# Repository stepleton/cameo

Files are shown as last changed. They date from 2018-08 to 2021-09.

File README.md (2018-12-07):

# Cameo

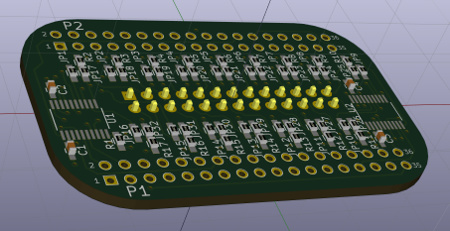
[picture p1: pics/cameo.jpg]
Cameo circuit board 3-D rendering


is a peripheral [cape](https://beagleboard.org/capes) circuit board that allows
the [PocketBeagle](http://beagleboard.org/pocket) single-board computer (which
uses 3.3V digital signals) to interface with 5V digital logic. It is built
around two Texas Instruments [TXS0108EPWR]( http://www.ti.com/product/TXS0108E)
or [TXB0108PWR]( http://www.ti.com/product/TXB0108) 8-bit bidirectional voltage
level translator ICs. Sixteen digital I/O signal lines are available.

Cameo is optimised for applications that take advantage of the two [PRU-ICSS](
https://beagleboard.org/pru) real-time coprocessors built into the chip-like
hybrid circuit that powers the PocketBeagle (a [TI AM3358](
http://www.ti.com/product/AM3358) SoC/[Octavo OSD3358](
https://octavosystems.com/octavo_products/osd335x/) SiP). The digital I/O lines
that pass through Cameo include all fourteen logic lines the PRUs can access
directly in either the input or output direction. The two remaining lines are
one that PRU 0 can use for output only and one it can use for input only, the
latter of which also happens to be the CLOCKIN line for the PRU's "parallel
capture" input mode. Alternatively, all lines may be used bidirectionally via
the AM3358's GPIO modules.

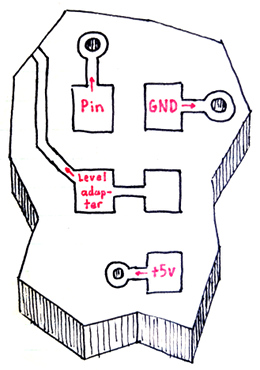
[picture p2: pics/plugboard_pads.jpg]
"Plugboard" diagram for a single pin

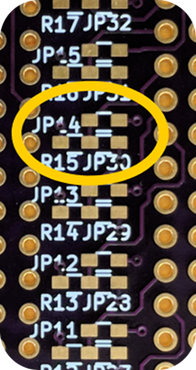
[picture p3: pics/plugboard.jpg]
Close-up of part of the "plugboard"


Cameo is "plugboard programmable": a pattern of jumper pads on the cape allow
each signal line to be individually tied/pulled to GND or +5V, or to be
[terminated](https://www.youtube.com/watch?v=rN9zjVK3Nrk) in a variety of ways,
all through installation of appropriate 0603 surface-mount components (or, in a
pinch, solder bridges or small fragments of wire). See the [plugboard pad map](
#plugboard-pad-map) for a diagram showing all of the "plugboard" pads.

## Fair warning

Cameo and associated hardware designs, software materials, and other resources
distributed alongside it are all made available for free with NO WARRANTY OF
ANY KIND. Any system that interfaces with Cameo could suffer malfunction, data
loss, physical damage, or other harms. Some of these effects could be permanent
and/or unrepairable. If you're not prepared to risk these consequences, don't
use Cameo.

## Example applications

* [Aphid installation Aphid](aphid/),
  a hardware emulator for Apple parallel port hard drives.

## Assembly and installation

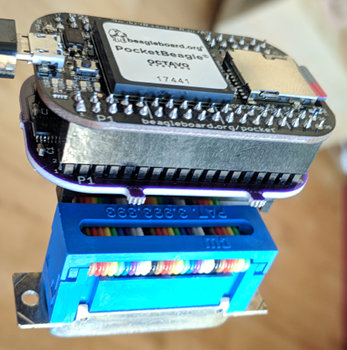
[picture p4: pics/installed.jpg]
A PocketBeagle/Cameo stack with a connector attached


Cameo is designed to mount underneath the PocketBeagle, preserving easy access
to the PocketBeagle's soft power button. The pin header for 5V digital I/O is
mounted on the underside of Cameo. With a short ribbon cable like the one in
the photo, the entire lightweight "stack" can dangle from a computer peripheral
port, as long as clearances and the security/fastness of the connector allow.

### Costs

To build a ready-to-use "stack" of your own from parts, you will need (prices
for informational purposes only; many are likely out-of-date):

* A PocketBeagle compact single-board computer ($25)
* A Cameo printed circuit board ($10 per board, **but sold only in packs of 3**
  from [OSH Park](https://www.oshpark.com/shared_projects/51GWu9Kw); shop around
  for deals by uploading the Gerber or KiCad project files in the
  [hardware directory](hardware) to online PCB manufacturers)
* Two TXS0108EPWR bidirectional level translator ICs ([e.g.](
  https://www.digikey.com/short/jr94zw); $1.66 each)
* Four 0.1μF MLCC 0603 surface mount capacitors ([e.g.](
  https://www.digikey.com/short/jr9znz); $0.10 each)
* One 240kΩ 0603 surface mount resistor ([e.g.](
  https://www.digikey.com/short/jrvd8z); $0.10 for just one)
* One 2x13 0.1" pitch pin header ([e.g.](https://www.digikey.com/short/jr9439);
  plastic shroud at your discretion; $0.30)
* Two 2x18 0.1" pitch pin headers ([e.g.](https://www.digikey.com/short/jr94b9);
  $0.69 each)
* Two 2x18 0.1" pitch sockets ([e.g.](https://www.digikey.com/short/jr94rq);
  $2.06 each)
* microSD memory card, 4GB or more, class 10 or better ($7 or so)
* Jumper and termination 0603 surface-mount components for I/O pins as required
  by your application (assuming the [Aphid](aphid/) configuration with 3 0Ω
  jumpers ([e.g.](https://www.digikey.com/short/jr9m80)) and 13 100Ω inline
  terminating resistors ([e.g.](https://www.digikey.com/short/j1rr2w)), $0.53
  altogether; jumpers are free if you make your own from scrap wire)

costing $52.15 in total. If you are willing to bond the PocketBeagle and Cameo
together permanently, you can omit the 2x18 sockets and save a bit over $4.

Some applications may benefit from adapting the 26-pin header on the bottom of
Cameo to a 25-pin DB-25 plug connector. To make this adaptor, you can use:

* 2x13 0.1" pitch socket with IDC crimp termination ([e.g.](
  https://www.digikey.com/short/jrbw3d), $0.58)
* DB-25 plug connector with IDC crimp termination ([e.g.](
  https://www.digikey.com/short/jrb2dj), $2.33)
* A short length (around 5cm) of 26-pin ribbon cable. ([e.g.](
  https://www.digikey.com/short/jrb2rr); $1.28 for a foot, ideally scrounged
  from a junk drawer for free)

adding to an additional $4.19.

### Assembly

Cameo is not an ideal starter project for hobbyists new to soldering
surface-mounted components; on the other hand, it doesn't have too many of
them, and they're not very tightly packed. The following diagram shows the
locations of essential SMD components on Cameo:

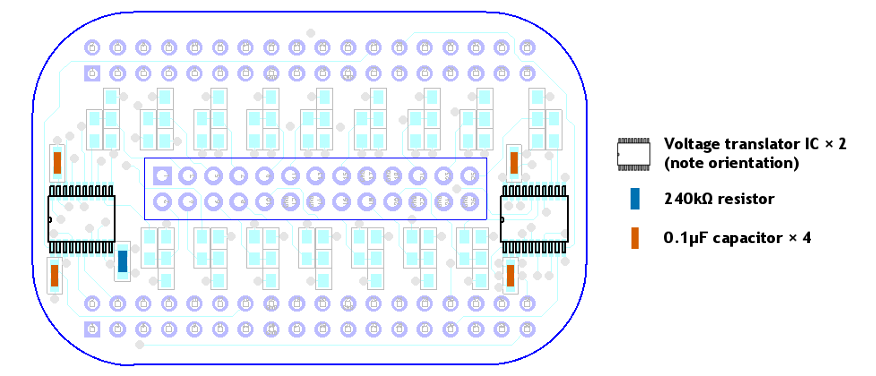
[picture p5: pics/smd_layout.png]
Locations of essential SMD components on Cameo


More SMD components will be required to set up the "plugboard" that connects
PocketBeagle signal lines to pins on the 5V I/O header. The specific nature and
configuration of these components are application-specific. See the
[introduction](#cameo) and the [plugboard pad map](#plugboard-pad-map) for more
details of the plugboard.

When assembling the Cameo board, it may be advisable to place the two voltage
translator ICs first, followed by the discrete SMD components and then by the
through-hole headers/connectors. **Remember, Cameo expects to be slung
underneath the PocketBeagle, so the 5V I/O header (centre) should emerge from
the bottom of the board, while the headers (or sockets) for connecting to the
PocketBeagle should emerge from the top.**

To connect to Cameo, the PocketBeagle will need sockets (or headers) emerging
from the **bottom** of its PCB. When mating Cameo to the PocketBeagle, be
certain of the correct orientation: if Cameo is orientated as shown above, the
USB connector on the PocketBeagle should be visible and pointing leftward.

Refer to online tutorials for making ribbon cable assemblies with IDC
connectors ([e.g.](https://startingelectronics.org/articles/IDC-ribbon-cable/))
to build an adaptor for the 5V I/O header. In general, it's best for the cable
between the two connectors to be as short as possible.

## Header pinout

The following pinout diagram represents Cameo's 26-pin 5V I/O header as viewed
from the underside of the Cameo PCB, with the PocketBeagle's USB connector
pointing upward.

| GPIO | PRU | PB pin | | Name | I/O pin | I/O pin | Name | | PB pin | PRU | GPIO |
|-----:|----:|---:|-|---:|:---:|:---:|:---|-|:---|:----|:-----|
| | | | | _n/c_  |  **1**  |  **2**  |  PEX3  | | P1.35  | 1 ⇆ | 2.24 |
| 1.10 | ⇆ 1 |  P1.32 | |  PEX1  |  **3**  |  **4**  | \PSTRB | | P2.9 | 0 ← | 0.15 |
| 1.11 | ⇆ 1 |  P1.30 | | PR/\W  |  **5**  |  **6**  | \PBSY  | | P2.35  | 1 ⇆ | 2.22 |
| 2.25 | ⇆ 1 | P1.4 | |  PEX2  |  **7**  |  **8**  | \PCMD  | | P1.2 | 1 ⇆ | 2.23 |
| 3.14 | ⇆ 0 |  P1.36 | | PD0  |  **9**  | **10**  |\PPARITY| | P2.24  | 0 → | 1.12 |
| 3.15 | ⇆ 0 |  P1.33 | | PD1  |  **11** | **12**  | ⏚ | | | | |
| | | | |  _n/c_ |  **13** | **14**  | ⏚ | | | | |
| 3.16 | ⇆ 0 |  P2.32 | | PD2  |  **15** | **16**  | _n/c_  | | | | |
| | | | | ⏚ |  **17** | **18**  |  PD3 | | P2.30  | 0 ⇆ | 3.17 |
| | | | | ⏚ |  **19** | **20**  |  PD4 | | P1.31  | 0 ⇆ | 3.18 |
| 3.19 | ⇆ 0 |  P2.34 | | PD5  |  **21** | **22**  | ⏚ | | | | |
| 3.20 | ⇆ 0 |  P2.28 | | PD6  |  **23** | **24**  | ⏚ | | | | |
| 3.21 | ⇆ 0 |  P1.29 | | PD7  |  **25** | **26**  | ⏚ | | | | |

The names of the 5V I/O pins reflect one of the example applications and should
be considered arbitrary. Pins marked _n/c_ connect to nothing; pins marked ⏚
are tied to ground.

The "PB pin" column shows which PocketBeagle header pin connects to Cameo's 5V
I/O header (through the 3.3V ⇆ 5V bidirectional voltage level translator ICs).

The "PRU" columns show which of the two PRU-ICSS real-time coprocessors in the
AM3358 are connected to each pin. A ⇆ symbol means that the corresponding
PocketBeagle pin can be configured either as an input to or an output of the
PRU; the ← and → symbols mean that the pin can only be a PRU input or output
respectively. Pins PD0-PD7 in particular map to PRU 0 GPIO bits 0-7.

The "GPIO" columns show how the pins correspond to I/O bits in the AM3358's
GPIO modules ("3.21" means module 3, bit 21). All pins may be accessed in any
direction through the GPIO subsystem.

For more detailed connectivity information, refer to the expansion header
tables in the [PocketBeagle reference manual](
https://github.com/beagleboard/pocketbeagle/wiki/System-Reference-Manual#71_Expansion_Header_Connectors).

Note finally that if an ordinary ribbon cable is used in an adaptor that
connects the 5V I/O header to a DB-25 plug connector, the pin numbering
patterns for both are different:

| DB-25 pin  | 1 | 2 | 3 | 4 | 5 |  6 |  7 |  8 |  9 | 10 | 11 | 12 | 13 |
|---|---|---|---|---|---|----|----|----|----|----|----|----|----|
| Header pin | 1 | 3 | 5 | 7 | 9 | 11 | 13 | 15 | 17 | 19 | 21 | 23 | 25 |

| DB-25 pin  | 14 | 15 | 16 | 17 | 18 | 19 | 20 | 21 | 22 | 23 | 24 | 25 |
|---|----|----|----|----|----|----|----|----|----|----|----|----|
| Header pin |  2 |  4 |  6 |  8 | 10 | 12 | 14 | 16 | 18 | 20 | 22 | 24 |

## Plugboard pad map

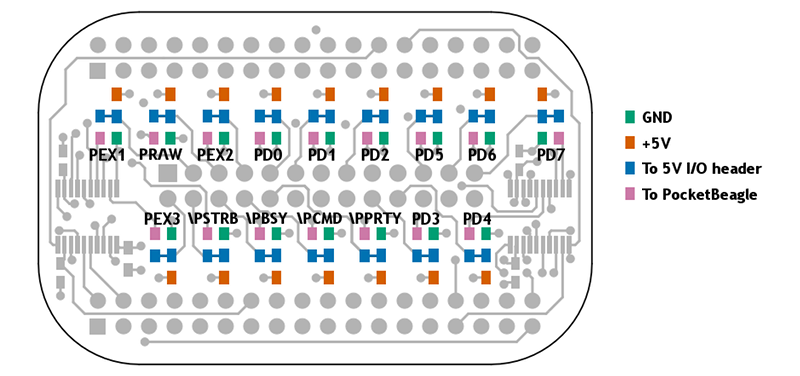
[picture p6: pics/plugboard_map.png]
Functional diagram of plugboard pads


This diagram shows a top-side view of Cameo. (In this view, the through-holes
for the 26-pin 5V I/O header (centre) are "flipped" about the header's long
(horizontal) axis, since the pins emerge from the underside of the board.)

The installation of jumpers, resistors, or other 0603 surface mount components
on each set of five pads shaped like ⠾, ⠻, or ⠷ determines whether and how the
labelled pin connects (through the voltage translator ICs) to the PocketBeagle.

## Development

Cameo was designed with [KiCad](http://kicad-pcb.org/) 4.  Project files and
derived products (Gerber files, etc.) are kept in the [hardware](hardware/)
subdirectory.

## Other notes

To the fullest extent possible, Cameo is released into the public domain.
Nobody owns Cameo.

## Acknowledgements

It would not have been possible for me to design Cameo without the help of the
following people and resources:

* Michael Welling's [pocketbeagle-cape-template](
  https://github.com/mwelling/pocketbeagle-cape-template).
* The [Sitara Processors Forum](https://e2e.ti.com/support/arm/sitara_arm) on
  the [TI E2E Community](https://e2e.ti.com/).
* Anonymous friends.

-- [_Tom Stepleton_](mailto:stepleton@gmail.com), 11 August 2018, London

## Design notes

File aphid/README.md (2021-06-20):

# Cameo/Aphid

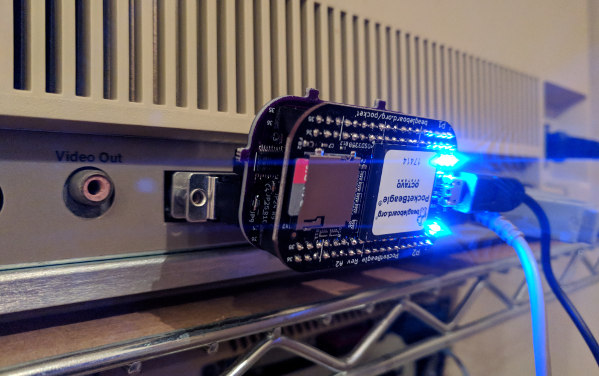
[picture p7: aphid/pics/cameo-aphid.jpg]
A PocketBeagle/Cameo stack with a connector attached


is a small Apple parallel port hard drive emulator based on the
[PocketBeagle](http://beagleboard.org/pocket) single-board computer and the
[Cameo](../README.md) 3.3V ⇄ 5V level adaptor cape. The hardware and software
described here aim to be a substitute for 5 MB (and also 10 MB) Apple
[ProFile](https://en.wikipedia.org/wiki/Apple_ProFile) external hard drives,
which were mainly used with Apple /// and Apple Lisa computers.

## Fair warning

Cameo/Aphid and associated hardware designs, software materials, and other
resources distributed alongside it are all made available for free with NO
WARRANTY OF ANY KIND. Any system that interfaces with Cameo/Aphid could suffer
malfunction, data loss, physical damage, or other harms. Some of these effects
could be permanent and/or unrepairable. If you're not prepared to risk these
consequences, don't use Cameo/Aphid.

**Additionally**: Cameo/Aphid is a new design that incorporates a number of
brand new, built-from-scratch software and hardware components. Although
considerable effort has been made to build a dependable emulator, Cameo/Aphid
still faces the test of time. It is possible, even likely, that some subtle
bugs have yet to be discovered and fixed.

## Gallery

Thumbnails link to high-resolution images, which may be helpful to people
assembling Cameo/Aphid. These images are not claimed to be illustrative of
good soldering technique.

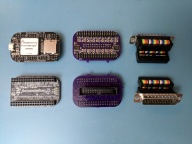
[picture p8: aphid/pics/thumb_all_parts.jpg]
Major Cameo/Aphid hardware components
[
Top and bottom views: PocketBeagle, Cameo, 5V I/O header to DB-25 adaptor.](
https://photos.app.goo.gl/s5zESxhNN7xtycam7)

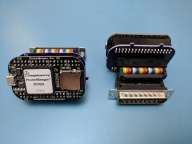
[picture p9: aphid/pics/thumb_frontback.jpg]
Cameo/Aphid hardware angled front and back views
[
Angled front and back views: Cameo/Aphid hardware components.](
https://photos.app.goo.gl/JWuywM5HkStonCPk9)

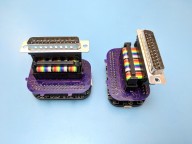
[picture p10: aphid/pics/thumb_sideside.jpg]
Cameo/Aphid hardware angled side views
[
Angled side views: Cameo/Aphid hardware components.](
https://photos.app.goo.gl/5HDvheUgoSHjGmFy6)

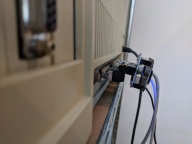
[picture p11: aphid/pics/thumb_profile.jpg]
Cameo/Aphid hardware on a Lisa, profile view
[
Profile view: Cameo/Aphid hardware installed on an Apple Lisa computer.](
https://photos.app.goo.gl/Pqm4weZKrUjdkRwC8)

A few additional photos are available in a [Google Images gallery](
https://photos.app.goo.gl/dgnkZrpXCz5ze1h9A).

## Usage

Cameo/Aphid is designed to be used in much the same way as a real ProFile hard
drive: it must be on and ready before the computer can be used; once the
computer is off again, Cameo/Aphid can be shut down and turned off.

Because Cameo/Aphid is based on the PocketBeagle, a single-board computer that
must boot an operating system to function, Cameo/Aphid takes longer to become
ready than a dedicated hardware emulator (e.g.
[X/ProFile](http://sigmasevensystems.com/xprofile), [IDEfile](
http://john.ccac.rwth-aachen.de:8000/patrick/idefile.htm)) does. Additionally,
like any modern computer (including the Apple Lisa), Cameo/Aphid prefers to
undergo a shutdown process before power is shut off.  To accomplish this at any
point after Cameo/Aphid is ready, press the [power button](
https://github.com/beagleboard/pocketbeagle/wiki/System-Reference-Manual#333_Powering_Down)
and wait for the "chasing lights" pattern (see below) to stop. It should only
take a few seconds.

(**UPDATE:** Full shutdown is not as important on Debian 9.5 and later OS
releases, as long as all the optional steps in the [installation instructions](
#full-instructions-for-manual-software-installation) have been carried out.
The [pre-made SD card image](#software-installation) was made in this way.
Robustness to power cuts is one step toward making Cameo/Aphid a suitable
replacement for Widget internal hard drives: further details of [improvements
targeting Widget replacement](#future-work) are below.)

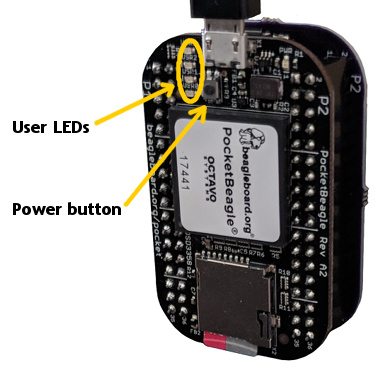
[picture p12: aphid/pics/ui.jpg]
Locations of the User LEDs and power button on the PocketBeagle


Cameo/Aphid uses the four "user LEDs" on the PocketBeagle to provide a visual
indication of its state. The light patterns you are most likely to see are
these:

1. **Just after Cameo/Aphid turns on**: The LEDs turn on one-by-one until all
   four are on.
2. **While the operating system is booting**: One LED is on nearly constantly,
   another blinks in a "heartbeat" rhythm; a third blinks with SD card access.
3. **While Cameo/Aphid software is starting up**: All four LEDs blink
   sequentially in a rapid "chasing" or "rotating" pattern. (**UPDATE:** This
   step will be skipped if all the non-optional steps in the [installation
   instructions](#full-instructions-for-manual-software-installation) are
   carried out, or if the [pre-made SD card image](#software-installation) is
   used.)
4. **When Cameo/Aphid is ready**: All four LEDs are on constantly.
5. **When Cameo/Aphid processes a disk command from the Apple**: All four LEDs
   blink off momentarily.
6. **During the shutdown process**: The chasing pattern resumes.
7. **When Cameo/Aphid is ready for power off**: The chasing pattern has frozen;
   at most one LED is on.

Finally, if Cameo/Aphid has encountered an unrecoverable error, the two central
user LEDs will slowly blink on and off. If this happens, try shutting down the
device by pressing the power button. Once the blinking stops, or if the power
button appears to have no effect after some time, try removing power from
Cameo/Aphid and then restoring it.

### Physical connections

Cameo/Aphid receives power from an ordinary Micro-B USB cable. Power
consumption data is hard to find for the PocketBeagle, but just about any USB
power source that can charge a phone reasonably well will probably work. A
computer with a USB-A port can supply power as well; don't be surprised by the
PocketBeagle's operating system making the PocketBeagle appear to be both a
network adaptor and a storage device.

Most installations will connect Cameo/Aphid to the Apple via a short adaptor
cable like the one described in the [main Cameo README.md](
../README.md#assembly). In this configuration, Cameo/Aphid dangles from the
Apple's DB-25 socket with no enclosure or physical support. If your Apple is
installed on an unpainted metal table or rack, take care that no components or
solder joints on the PocketBeagle or Cameo circuit boards rest on any metal
surface: stray electrical connections could result.

The electronics on the Cameo level translator cape do not work well with long
parallel cables. Little work has been carried out to determine the longest
cable that can work with Cameo/Aphid, but lengths between 50cm (20") and "as
short as possible" are probably preferable. Cameo/Aphid will work when attached
to a Widget hard drive ribbon cable inside a Lisa 2/10. Apple II users should
note that a typical Apple II ProFile interface card installation uses a
somewhat lengthy cable to connect the card to the parallel port. (Cameo/Aphid
has not yet been tested on an Apple II.)

### Hard drive images

Cameo/Aphid stores data from the simulated hard drive in an ordinary file on
the PocketBeagle's microSD card. This file has no metadata and a very simple
format: just as a 5 MB ProFile stores 5,175,296 bytes of data, a corresponding
hard drive image file is a 5,175,296-byte file; and just as a ProFile block is
532 bytes, each contiguous 532-byte chunk of the image file holds data from one
of the simulated drive's blocks. These blocks are arranged sequentially in the
file, starting from block $0000 and counting up to block $25FF.

(Aside: neither Cameo/Aphid nor the Apple parallel hard disk protocol itself
distinguish between "tag bytes" or "data bytes", even though these divisions of
a block are important to Lisas.)

Cameo/Aphid does not require image files to be only 5,175,296 bytes in size. A
10,350,592-byte image file causes Cameo/Aphid to emulate a 10 MB ProFile
(complete with the "spare table" data structure that announces it as such). An
enormous range of non-standard sizes are also supported: Cameo/Aphid will do
its best to serve hard drive image files of any size up to 8,890,613,228 bytes
(!), though images larger than a few dozen megabytes have not been tested.

(Note that many operating systems for your Apple will not know what to do with
hard drives that have non-standard sizes, and some older operating systems may
only work with 5 MB ProFiles.)

A microSD card initialised from the [pre-built software image](
#software-installation), or any other installation that makes use of a
[separate FAT32 partition for drive image storage](
#4-optional-prepare-a-separate-partition-for-cameoaphid-drive-images), can be
plugged into most modern computers and accessed like an ordinary flash drive.
Some computers may show two drives, one called `rootfs` and another called
`CAMEO_APHID`: the `CAMEO_APHID` drive is the home for hard drive images, and
`rootfs` should be left alone. (Windows users who don't see a drive after
plugging in their microSD cards may need to use the "Disk Management" or
"Create and format hard disk partitions" control panel to assign a drive letter
to the SD card's `CAMEO_APHID` partition.)

On the `CAMEO_APHID` drive, hard drive image files are any that end in
`.image`, with `profile.image` being the image file that Cameo/Aphid uses on
start-up.  It is fine to copy, rename, and otherwise manage hard drive image
files like any other kind of file, but Cameo/Aphid will not work if no file
called `profile.image` exists.

The operating system that runs on Cameo/Aphid's PocketBeagle computer is a
version of Debian Linux. In standard Cameo/Aphid setups, the `CAMEO_APHID`
partition is mounted at `/usr/local/lib/cameo-aphid`. If you have a network
connection to the PocketBeagle, which usually establishes automatically when
you plug a PocketBeagle into a modern computer's USB port, you can use ordinary
communications utilities (typically SSH, SCP) for command line access and file
transfer with the device. (For more guidance on connecting to your
PocketBeagle, see the [BeagleBone "Getting Started" guide](
http://beagleboard.org/getting-started). You may need to use the IP addresses
192.168.6.2 or 192.168.7.2 instead of the `beaglebone.local` convenience name.)

In the future, it may become possible to upload and download drive images via a
web browser.

:warning: **Be sure not to change or replace the hard drive image file while
the Apple is actively reading from or writing to the simulated disk drive.
After altering the image file, you must shut down and restart Cameo/Aphid
before the Apple attempts to access the drive.**

### For programmers

Cameo/Aphid allows the Apple to restart or shut down ProFile emulation via
specially-formatted writes. The Apple can use this "control writes" mechanism
to change the hard drive image file that Cameo/Aphid uses for reads and writes.

The following "control writes" are made to the non-existent sector $FFFFFD,
with $FE as the retry count parameter and $AF as the sparing threshold
parameter:

- Writing sector data that begins with the null-terminated string "HALT" (i.e.
  `$48,$41,$4C,$54,$00`) causes Cameo/Aphid to cease ProFile emulation. This
  does not shut down the PocketBeagle itself. When emulation is halted, the
  four user LEDs will blink sequentially in a rapid "chasing" or "rotating"
  pattern.

- Writing sector data that begins with "IMAGE:" (i.e. `$49,$4D,$41,$47,$45,$3A`)
  and then continues with the null-terminated name of a file residing in the
  working directory of the Cameo/Aphid ProFile emulator Python program, causes
  Cameo/Aphid to restart ProFile emulation with this file as the hard drive
  image that it uses for reads and writes. For extra safety, the filename must
  end in ".image".

- Writing any other sector data will cause Cameo/Aphid to restart ProFile
  emulation with the same hard drive image file that it was using prior to the
  write.

Restarting ProFile emulation takes less than a second, but no effort has been
made to determine what happens if the Apple tries to interact with Cameo/Aphid
during this interval.

## Making your own

At present, the only way to get your own Cameo/Aphid is to build one. Finished
assemblies are not known to be available anywhere, but since all the
Cameo/Aphid-specific software and hardware designs are released into the public
domain, anyone is free to build and sell them without seeking anyone's
permission or negotiating any license terms. The parts cost for a complete,
ready-to-use Cameo/Aphid setup is around $55 for a home hobbyist; manufacture
in limited quantities might lower this figure somewhat.

Building Cameo/Aphid "from scratch" requires some proficiency in the following
skills:

* Soldering surface-mounted components, including ICs in small (TSSOP) packages
  with a somewhat narrow (0.65mm) pin pitch.
* ~~"Linux stuff": SSH, using the command line, `sudo`, editing configuration
  files, that sort of thing.~~

If you think you *might* be able to do it, you probably can, with patience.

### Hardware assembly

Cameo/Aphid uses the Texas Instruments [TXS0108E](
http://www.ti.com/product/TXS0108E) series of level translator ICs. A complete
parts list for assembling Cameo/Aphid appears in the [main Cameo README.md](
../README.md#costs). Nearly all installations will want to use the short
adaptor cable described there so that Cameo/Aphid can dangle from a parallel
port on the Apple.

This diagram shows the locations and values of all of the SMD components that
should be installed on the Cameo PCB to support Aphid:

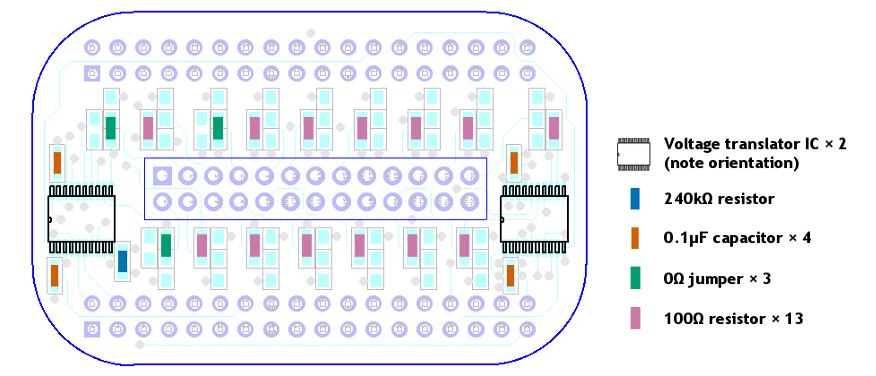
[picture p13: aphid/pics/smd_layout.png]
All surface mount components for Cameo/Aphid


The jumpers on the "plugboard" pads establish connections between the 5V I/O
header pins and the level translator chip. The current design uses 100Ω
terminating resistors for these connections to support longer cables between
Cameo/Aphid and the Apple; in general, though, shorter cables are preferable.
Take care to replicate the positioning of all components exactly---the
plugboard pads are tightly spaced, and it's especially easy to put a jumper in
the wrong place.

The [main Cameo README.md](../README.md#assembly) has more detailed assembly
information.

When building a DB-25 port adaptor to connect Cameo to the Apple: sometimes the
Apple's parallel port will have plastic material or a metal shim blocking pin
7, which is unused. If this is the case for your system, remove pin 7 (the
centre pin in the top, wider row of pins) from the adaptor's DB-25 plug with a
pair of pliers. Some force may be required.

### Software installation

The easiest way to install Cameo/Aphid software on a microSD card is to "flash"
a pre-built software image onto the card: it requires no skill with "Linux
stuff". Download a software image (made with the instructions below) from [this
link](http://stepleton.com/cameo_aphid_image.php) (note: a circa 600 MB file,
give or take several dozen MB), then follow [these instructions](
https://beagleboard.org/getting-started#update) on using Etcher to install the
image onto a good quality microSD card (4GB or more, preferably [Class
10/U1/V10](https://en.wikipedia.org/wiki/Secure_Digital#Speed_class_rating) or
better).  Once flashed, the card can be plugged into the PocketBeagle, and
Cameo/Aphid will be ready for [use](#usage), appearing to the Apple as an empty
(uninitialised) ProFile. The following instructions can then be ignored.

(Technical note: The pre-built software image stores the ProFile drive image on
a separate 512 MB FAT32 partition with the label `CAMEO_APHID`, which it mounts
at `/usr/local/lib/cameo-aphid`. Only changes to files in this directory will
persist between PocketBeagle power cycles and reboots; all changes to all other
files and directories are temporary.)

#### Full instructions for manual software installation

The Cameo/Aphid software comprises

* firmware programs for each of the PocketBeagle's two PRU-ICSS real time
  I/O coprocessors ("PRUs" for short)
* a [Python program](profile.py) that runs on the PocketBeagle's main
  processor, interpreting sector read/write commands from the Apple and
  applying them to a hard drive image file
* a [Python plugin module](profile_plugins.py) for the program that provides a
  "magic blocks" facility: reads and writes to these blocks can modify the
  behaviour of the emulator or support a variety of operations unrelated to
  ordinary hard drive data storage
* a collection of Python module plugins that exploit this capability to provide
  a [system information service](profile_plugin_FFFEFD_system_info.py), a
  [file management service](profile_plugin_FFFEFE_filesystem_ops.py), and a
  [key/value store](profile_plugin_FFFEFF_key_value_store.py)
* a [software program for the Apple Lisa](selector), taking the form of a
  bootable hard drive image, that uses the "magic block" plugins to provide a
  versatile text-based interface for selecting and managing hard drive images.

The software targets the following BeagleBone.org Debian Linux disk images:

* `Debian 10.3 2020-04-06 4GB SD IoT` **(Not recommended: see below)**
* `Debian 10.0 2019-07-07 4GB SD IoT`
* `Debian 9.9 2019-08-03 4GB SD IoT`
* `Debian 9.5 2018-10-07 4GB SD IoT`
* `Debian 9.5 2018-08-30 4GB SD IoT`
* `Debian 9.4 2018-06-17 4GB SD IoT`
* `Debian 9.3 2018-03-05 4GB SD IoT`

available [here](http://beagleboard.org/latest-images). If none of these are
listed under "Recommended Debian images", look for them under "Older Debian
images" further down on the page. Newer images may work but have not been
tested.

(The `Debian 10.3 2020-04-06 4GB SD IoT` image is not recommended as it lacks
support for the optional [power-off robustness mechanism](
#10-optional-enable-power-off-robustness-for-the-root-filesystem) described
below. [A feature request](
https://github.com/beagleboard/Latest-Images/issues/80) to restore this support
in future BeagleBone.org Debian Linux disk images has been filed.)

Follow these steps to set up the Cameo/Aphid software on your PocketBeagle:

#### 1. Install the Linux disk image onto a new microSD card.

Download one of the Debian Linux disk images specified above from the
BeagleBoard.org [Latest Firmware Images](http://beagleboard.org/latest-images)
page (preferably the Debian 9.9 image). Follow the [instructions](
https://beagleboard.org/getting-started#update) to install it on a good quality
microSD card. (The PocketBeagle used to develop the Cameo/Aphid software had a
card with a Class 10 [speed class rating](
https://en.wikipedia.org/wiki/Secure_Digital#Speed_class_rating).)

#### 2. Enable remoteproc/RPMsg for controlling the PocketBeagle's PRUs (Debian 9.3 only).

:warning: **NOTE: This step is only required for the `Debian 9.3 2018-03-05 4GB
SD IoT` Debian Linux disk image.**

Boot your PocketBeagle and connect to it via SSH. As above, this usually
entails plugging the PocketBeagle into your computer's USB port and logging in
to `beaglebone.local` as user `debian` with password `temppwd`. For more
guidance on connecting to your PocketBeagle, see the [BeagleBone "Getting
Started" guide](http://beagleboard.org/getting-started).

Once in, edit the file `/boot/uEnv.txt` with superuser privileges. Find the
line containing this text:

    #uboot_overlay_pru=/lib/firmware/AM335X-PRU-UIO-00A0.dtbo

and just beneath it, add a new line with the following text:

    uboot_overlay_pru=/lib/firmware/AM335X-PRU-RPROC-4-9-TI-00A0.dtbo

Take care to avoid typos or copy/paste errors: mistakes in `/boot/uEnv.txt` can
leave your microSD card unbootable, and you'd need to start over from Step 1.

#### 3. Compile the firmware and prepare a 5 MB drive image.

Copy this directory and all of its contents to the PocketBeagle (usually
accomplished via SCP to `beaglebone.local`). It's fine to place the copy
anywhere in the home directory of the `debian` user.

Log back into your PocketBeagle and cd into the copy of this directory. Begin
the compile by typing `make`. Compilation of the firmware and decompression of
the drive image (a 5,175,296-byte file called `profile.image` preloaded with the
[Cameo/Aphid selector](selector/), unpacked from [selector/selector.image.zip](
selector/selector_image.zip)) takes a couple dozen seconds.

#### 4. (optional) Prepare a separate partition for Cameo/Aphid drive images.

This optional step establishes a separate FAT32 partition on the SD card for
ProFile drive image storage---required for setting up the robustness to power
failure described in Step 8. First, from the directory created by Step 3,
execute the script `setup_dos_partition_part1.sh` with superuser privileges,
optionally with a size argument in bytes (a 512 MB partition is created by
default). When this completes, reboot the PocketBeagle. Log in again, return to
the same directory, and execute the script `setup_dos_partition_part2.sh`.

Together, these scripts modify the SD card's partition table to add a
partition, create a mount point for the partition at
`/usr/local/lib/cameo-aphid`, create a FAT32 filesystem on the partition, and
direct the OS to mount the new partition there on boot.

#### 5. Install the Aphid software, firmware, drive image, and service script.

From the directory created by Step 3, execute the command `make install` with
superuser privileges. This command creates a permanent installation directory
for the Cameo/Aphid software and drive image, then installs a file that tells
the PocketBeagle to configure and start the entire Cameo/Aphid emulator system
on boot. The specific steps that `make install` performs are:

- Copy the PRU-ICSS firmware files `aphd_pru0_datapump.fw` and
  `aphd_pru1_control.fw` to the `/lib/firmware` directory.
- Copy those files to `/lib/firmware` a second time, but use the filenames
  `am335x-pru0-fw` and `am335x-pru1-fw`, which causes the kernel to load the
  firmware into the PRU-ICSS coprocessors at boot time.
- Copy the device tree overlay file `PB-CAMEO-APHID.dtbo` to the
  `/lib/firmware` directory.
- Create the directory `/usr/local/lib/cameo-aphid` (if not already present)
  and copy the drive image file `profile.image` and the Python program
  `profile.py` inside.
- Copy the `cameo-aphid.service` service script to `/lib/systemd/system`.

#### 6. Tell the PocketBeagle to use the Cameo/Aphid device tree overlay.

With superuser privileges, and in the directory created by Step 3, run the
`setup_device_tree_overlay.sh` script. This tells the Linux kernel running on
the PocketBeagle to load the `PB-CAMEO-APHID.dtbo` device tree overlay on
startup, which causes the PocketBeagle to configure its low-level facilities at
boot time for communication with an Apple through the Cameo level translator
cape. (Specifically, it primarily sets up the "pinmux", which controls how
devices built into the PocketBeagle like the PRUs connect to physical
PocketBeagle pins.)

#### 7. Tell the PocketBeagle to start the Cameo/Aphid emulator system on boot.

With superuser privileges, execute the command `systemctl enable cameo-aphid`.

Basic software installation is complete after this step. The next time the
PocketBeagle boots, the Cameo/Aphid emulator should be ready to emulate a 5 MB
Apple ProFile hard drive. See the [Usage](#usage) section of this file for
usage instructions.

The following steps are optional, but useful.

#### 8. (optional) Disable unneeded Linux system facilities.

With superuser privileges, and in the directory created by Step 3, run the
scripts `setup_trim_services.sh` and `setup_trim_misc.sh`. This disables some
PocketBeagle system facilities that aren't useful for hard disk emulation,
which shaves a few seconds off the time it takes Cameo/Aphid to be ready after
power-on.

#### 9. (optional) Apply optional operating system configuration changes.

With superuser privileges, and in the directory created by Step 3, run the
`setup_os_config_changes.sh` script, which applies miscellaneous beneficial
changes to the operating system's configuration. Refer to the contents of the
script for details on what the changes do and why.

#### 10. (optional) Enable power-off robustness for the root filesystem.

Only if Step 5 has been carried out, run the script `setup_overlayroot.sh` with
superuser privileges. This causes the PocketBeagle to boot into a mode where
files on the root filesystem cannot be changed; instead, changes are stored
temporarily in the PocketBeagle's RAM and are lost when the PocketBeagle shuts
down or reboots. The separate filesystem for drive images set up in Step 5 is
not affected and writes to emulated ProFiles will still be saved.

This step makes it safer to shut off power to Cameo/Aphid without undergoing
the formal shutdown process triggered by pressing the power button. The root
filesystem cannot be damaged by uncommitted writes, and changes to the FAT32
filesystem containing drive image data are frequently committed to the SD card.

## Technical overview

The information in this section is not necessary to build or use Cameo/Aphid,
but may be of interest to people interested in making modifications or
investigating similar applications.

Cameo/Aphid takes advantage of the PocketBeagle's [PRU-ICSS coprocessors](
http://processors.wiki.ti.com/index.php/PRU-ICSS) ("PRUs" for short) to achieve
a dependable implementation of the Apple parallel port hard drive protocol.
Like the I/O subsystems on modern PCs or the [channel controllers](
https://en.wikipedia.org/wiki/Channel_I/O) on mainframes of yore, the PRUs
handle the timing-sensitive low-level details of the protocol so that the main
processor can attend to various custodial tasks on its own schedule.

The PocketBeagle's [AM3358 SoC](http://www.ti.com/product/AM3358) includes two
PRUs. Each PRU has a different pattern of direct connectivity to the pins of
the PocketBeagle's two expansion headers. PRU 0 can access eight pins in either
the input or output direction plus four more as inputs only and two more as
outputs only; PRU 1 can access six pins in either the input or output direction
plus two more as inputs only. Cameo's pair of level translator ICs can
accommodate only 16 signal lines altogether, so of these 22 pins, Cameo passes
through all 14 two-way signals, one PRU 0 input-only line, and one PRU 0
output-only line.

Inspired by this arrangement and the nature of the Apple parallel port hard
drive protocol, the overall Cameo/Aphid design allocates PRU 0 to handle
clocked data transfer and calculation of the (odd) parity signal for the
parallel port's eight bidirectional I/O lines, and it allocates PRU 1 to handle
the parallel port's three other control lines. Notionally, PRU 1 supervises the
handling of all transactions with the Apple; PRU 0 is the "data pump" that
streams bytes to and from the Apple on PRU 1's request, while the Python
program running on the PocketBeagle's main ARM processor loads and saves block
data in the drive image file whenever PRU 1 instructs it to do so.

Although PRU 0 can directly access eight of the I/O pins as either inputs or
outputs, a PRU cannot select or change which of these "direct access" modes is
in effect. Unfortunately, that means that these modes aren't suitable for
bidirectional I/O, even though Cameo is otherwise well-organised to facilitate
this: PRU 0 simply can't alternate between sending and receiving data via
direct access. So, to manage the eight data lines, PRU 0 falls back to using
the AM3358's GPIO registers---a method available to either PRU. Still, the
division of labour between both PRUs is convenient: it allows PRU 0 to respond
quickly to the Apple's \PSTRB clocking signal and to compute the correct value
for \PPARITY (both accessed by PRU 0 directly) whilst PRU 1 and the ARM are
busy doing other things.

PRU 0 and PRU 1 do most of their information sharing through the PRU shared
memory region, with data transfer requests and completions signaled via
interrupts. Communication between PRU 1 and the ARM uses Linux's [RPMsg](
https://www.kernel.org/doc/Documentation/rpmsg.txt) I/O framework, and because
RPMsg messages can be no larger than 512 bytes, multiple messages are necessary
to transfer block data between the ARM and the PRUs.

All three major Cameo/Aphid software/firmware components are extensively
commented, so further detail here may be redundant. Good starting places for
reading Cameo/Aphid source code are:

* [profile.py](profile.py): the entire Python program that runs on the ARM.
* [aphd_pru0_datapump.asm](firmware/aphd_pru0_datapump/aphd_pru0_datapump.asm):
  the entire source code for the PRU 0 "data pump" firmware.
* [aphd_pru1_control.cc](firmware/aphd_pru1_control/aphd_pru1_control.cc): core
  of the PRU 1 "control" firmware.

## Future work

Potential future improvements and new features for Cameo/Aphid include:

* Widget emulation (hard, since many more low-level hard drive commands are
  required for complete emulation).

* Support for Lisa 2/10 drive bay installation: largely complete.

  - :heavy_check_mark:
    Increased robustness to power cuts allow Cameo/Aphid to operate within the
    enclosed drive bay, even though a Lisa powering down can shut down internal
    hard drives without warning.

  - :heavy_check_mark:
    The longer ribbon cable that the 2/10 uses to connect to the Widget in the
    drive bay causes signal quality issues that can lead to malfunctions,
    likely due to ringing or reflections that can confuse the TXS0108E level
    adaptor ICs about signal direction. Inline 100Ω terminating resistors on all
    Cameo signal lines except PEX1, PEX2, and PEX3 appear to dampen the ringing
    well enough for Cameo/Aphid to work.
  
  - :heavy_check_mark:
    When a Lisa 2/10 is powered on, it will attempt to boot from its internal
    parallel port in around 22 seconds. For Cameo/Aphid installed internally to
    make use of the Widget hard drive's power supply, it must boot and be ready
    to emulate a hard drive in a similar amount of time: if it's too slow, the
    Lisa will present a boot error and require user input. Improvements to the
    Cameo/Aphid boot procedure now reduce startup time below the critical
    threshold required for automatic booting.

  - :man_shrugging:
    Finally, some substitute for the green hard drive status LED should be
    devised.

* A web browser interface for hard drive image file management: by plugging
  Cameo/Aphid into a modern computer and visiting a designated web address, the
  user can upload and download hard drive image files to an image library, as
  well as select an "active" image that Cameo/Aphid serves to the Apple.
  (Even a relatively small microSD card could easily store several thousand
  hard drive image files.)

* An Aphid-specific level translator PCB design instead of configurable,
  multi-purpose Cameo and its plugboard: it may be possible for the PCB to be
  a two-layer design, offering significant cost advantages. An integral DB-25
  plug connector could be an additional feature.

## Other notes

To the fullest extent possible, Cameo/Aphid is released into the public domain.
Nobody owns Cameo/Aphid.

The modified linker command files for the
[PRU 0](firmware/aphd_pru0_datapump/AM335x_PRU.cmd) and
[PRU 1 firmware](firmware/aphd_pru1_control/AM335x_PRU.cmd) bear copyright
statements by Texas Instruments and are mostly generated automatically by TI's
[Code Composer Studio](http://www.ti.com/tool/CCSTUDIO) IDE.

All other source code files associated with Aphid are forfeited into the public
domain with no warranty. For details, see the [LICENSE](../LICENSE) file.

Apple, ProFile, and Lisa are [Apple Inc.](https://www.apple.com/) trademarks.
PocketBeagle, BeagleBone, and BeagleBone.org are [BeagleBone.org](
http://beaglebone.org) trademarks. Sitara and Code Composer Studio are
[Texas Instruments Inc.](http://www.ti.com) trademarks.

## Acknowledgements

It would not have been possible for me to create Cameo/Aphid without the help
of the following people and resources:

* [Dr. Patrick Schäfer](http://john.ccac.rwth-aachen.de:8000/patrick/index.htm),
  whose [IDEfile](http://john.ccac.rwth-aachen.de:8000/patrick/idefile.htm) and
  [UsbWidEx](http://john.ccac.rwth-aachen.de:8000/patrick/UsbWidEx.htm) project
  pages were invaluable to the project (as were actual UsbWidEx and IDEfile
  devices of my own).
* [bitsavers.org](http://bitsavers.org)'s archived technical documentation.
* The [Sitara Processors Forum](https://e2e.ti.com/support/arm/sitara_arm) on
  the [TI E2E Community](https://e2e.ti.com/).
* Blog posts and other materials by
  [Dr. Andrew Wright](http://theduchy.ualr.edu/), Jason Kridner,
  [Dr. Mark A. Yoder](https://elinux.org/BeagleBoard_Education_Workshops),
  [Ken Shirriff](http://www.righto.com), and others.
* Encyclopedic references like the
  [AM335x Technical Reference Manual](http://www.ti.com/lit/pdf/spruh73), the
  [PRU Assembly Instruction User Guide](http://www.ti.com/lit/pdf/spruij2), the
  [AM335x PRU-ICSS Reference Guide](
  https://elinux.org/images/d/da/Am335xPruReferenceGuide.pdf), the
  [PRU Assembly Language Tools User's Guide](
  http://www.ti.com/litv/pdf/spruhv6b), the
  [PRU Optimizing C/C++ Compiler v2.2 User's Guide](
  http://www.ti.com/litv/pdf/spruhv7b), and the
  [PocketBeagle System Reference Manual](
  https://github.com/beagleboard/pocketbeagle/wiki/System-Reference-Manual).
* Pointers from zmatt of the [`#beagle` IRC channel on irc.freenode.net](
  http://beagleboard.org/chat).
* The entire [LisaList](https://groups.google.com/forum/#!forum/lisalist)
  community.
* Torbjörn Nordlindh and Stefan Wärn for information and testing leading to
  Apple /// and recent macOS compatibility.
* Anonymous friends.

## Revision history

11 August 2018: Initial release.
(Tom Stepleton, [stepleton@gmail.com](mailto:stepleton@gmail.com), London)

4 October 2018: Debian 9.5 support, power-cut resilience, boot time,
SD card longevity (Tom Stepleton)
- Debian 9.5 support: adapt to changes to resource table field names and layout.
- Power-cut resilience: introduce a separate FAT32 partition for drive images.
- Power-cut resilience: add overlayfs protection for root filesystem.
- Boot time: disable unused Linux services.
- SD card longevity: only sync drive image changes every four seconds.

20 October 2018: Update to the BeagleBoard.org 2018-10-07 Debian 9.5 image.
(Tom Stepleton)

7 December 2018: Inline 100Ω terminating resistors on signal lines for improved
performance with longer cables. (Tom Stepleton)

6 November 2019: Debian 9.9 support. (Tom Stepleton)

12 January 2020: Upgraded `profile.py` to Python 3.5; the Apple can now command
the emulator to use a different boot image or cease emulation. (Tom Stepleton)

24 January 2021: Many changes, including the "magic blocks" plugin mechanism,
the Selector program, and a bug fix that allows a Lisa to boot reliably from a
Cameo/Aphid attached to the upper port of a 2-port parallel expansion card.
(Tom Stepleton)

3 February 2021: Automatic firmware loading on startup and the addition of a
device tree overlay dramatically reduce boot times, making it feasible to
install Cameo/Aphid inside a Lisa 2/10. (Tom Stepleton)

6 February 2021: 10 MB ProFile emulation and support for arbitrarily-sized drive
images. (Tom Stepleton)

15 February 2021: Eliminate timeouts in PRU0 firmware (and add timeouts to PRU1
firmware in strategic places) for better MacWorks compatibility. (Tom Stepleton)

19 June 2021: Stop requiring writes to be 532 bytes long (some Apple /// OSs
write only 512 bytes). Manually apply changes like the ones from [this patch](
https://github.com/RobertCNelson/boot-scripts/commit/b61125c1485bee929340cacc06c85c6fcfd678bc#)
to the 10.0 IoT image for USB compatibility with modern MacOS. (Tom Stepleton)

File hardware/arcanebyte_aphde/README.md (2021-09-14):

# Apple Parallel Hard Drive Emulator

The Apple Parallel Hard Drive Emulator is derived from the Cameo/Aphid cape
for the [PocketBeagle](http://beagleboard.org/pocket) single-board computer.
It is intended as a modified form-factor with some enhancements over the
cape design.

## Rev A

The Rev A design uses the same components as the cape, including two Texas
Instruments [TXS0108EPWR]( http://www.ti.com/product/TXS0108E) 8-bit bidirectional voltage
level translator ICs. The 100ohm resistors are included for better
compatibility with the Lisa 2/10, but YMMV. The board is designed to plug
directly into the parallel port without a cable.

## Rev B

The Rev B design forgoes the TXS0108 chips for BSS138 logic level converters.
This design has shown to be more compatible with the Apple Lisa 2/10 using the
internal widget cable. A small adapter can be used to convert from the 26-pin
IDC cable to the DB25 interface provided on the board.

## Other notes

In the spirit of Cameo, this modified design is released into the public domain.
There is no warranty and any improvements are welcome.

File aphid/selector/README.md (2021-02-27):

# Cameo/Aphid Selector

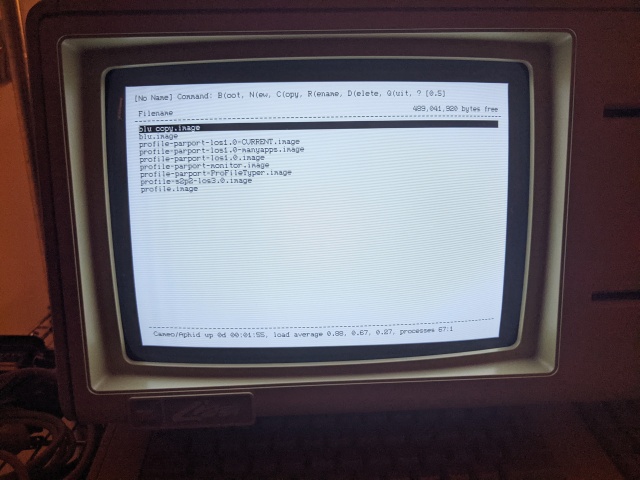
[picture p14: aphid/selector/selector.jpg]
The Selector running on a Lisa 1 The Selector in real life


The Cameo/Aphid drive image selector program ("the Selector" for short) is a
program for Apple Lisa computers that controls a [Cameo/Aphid ProFile hard
drive emulator](https://github.com/stepleton/cameo/tree/master/aphid). Most
Selector users will use the Selector to create, manange, and boot hard drive
images that belong to a catalogue of hard drive images on their Cameo/Aphid
devices.

## Installation

This README file is a placeholder; before long, additional information and
installation instructions will be provided here. For now, if you have a
Cameo/Aphid running the most current version of the Cameo/Aphid software
listed [in the Cameo/Aphid README](../README.md#software-installation), you
may do the following:

1. Back up your Cameo/Aphid microSD card.

2. On a modern computer, copy these files into the microSD card's FAT
   partition (called `CAMEO_APHID`): `profile.py`,
   `profile_plugin_FFFEFC_selector_rescue.py`,
   `profile_plugin_FFFEFD_system_info.py`,
   `profile_plugin_FFFEFE_filesystem_ops.py`,
   `profile_plugin_FFFEFF_key_value_store.py`, and `profile_plugins.py`. Note
   that you will overwrite the existing `profile.py`.

3. Rename any existing file on the FAT partition called `profile.image` to
   something else.

4. Download `selector.image.zip`, unpack `selector.image` and copy it to the
   microSD card's FAT partition, and rename it `profile.image`.

## Manual and more

There is a detailed [user's manual](MANUAL.md) and a document that describes
[the protocol the Selector uses](PROTOCOL.md) to control the Cameo/Aphid.

-- _[Tom Stepleton](mailto:stepleton@gmail.com), 17 January 2021, London_

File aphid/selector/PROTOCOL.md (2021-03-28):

# "Magic blocks" used by the Cameo/Aphid drive image selector

The Cameo/Aphid drive image selector program ("the Selector" for short) is a
computer program for the Apple Lisa that allows you to create, manage, and boot
from ProFile drive image files on a Cameo/Aphid ProFile hard drive emulator.
Behind the scenes, the Selector accomplishes this by sending specially
formatted read and write commands to the drive emulator that target unusual
hard drive blocks.

The Selector is not the only program that can use these "magic blocks", and any
hard drive emulator that understands these special reads and writes will be
compatible with the Selector. This document describes the format of these reads
and writes for the benefit of anyone who wishes to take advantage of this
capability.

This document was created as part of the Cameo/Aphid hard drive emulator
project at [https://github.com/stepleton/cameo/tree/master/aphid].

## Block `FFFFFF`: "Magic block" capability identification

The Selector reads from block `FFFFFF` to identify whether the connected drive
is a ProFile emulator that supports the "magic block" protocol described here.
If bytes $20-$2B of the returned block are `Cameo/Aphid ` and bytes $2C-$2F are
a 32-bit integer greater than or equal to $30303031 (i.e. `0001`), then the
Selector may assume that it is talking to a compatible emulator.

Note that ordinary ProFile hard drives respond to reads on block `FFFFFF` with
"artificial" block data that contains information about the hard drive. Drives
with ROM version $0398 that allocate no bad blocks or spare blocks only need
bytes $00-$1F to encode this information, so the adjacent bytes occupied by the
"magic block" capability identifier will not interfere with it.

## Block `FFFFFD`: "Built-in" emulator commands

Writes to block `FFFFFD` with write count and sparing threshold parameters `FE`
and `AF` respectively will issue "built-in" commands to the hard drive
emulator. These commands are encoded in the block data written to the drive.
("Built-in" refers to an implementation detail of the Cameo/Aphid emulator and
is not important to this description.) There are currently two "built-in"
commands:

1. If bytes $00-$03 of the block data are `HALT`, the emulator will immediately
   shut down after completing any uncommitted writes to the currently open
   hard drive image file.

2. If bytes $00-$06 of the block data are `IMAGE:`, then subsequent bytes
   should be a null-terminated string specifying the name of a hard drive image
   file. If this filename corresponds to an actual file, the emulator will flush
   any uncommitted writes to the hard drive image file currently in use, then
   then immediately close that file and open the specified hard drive image
   file in its place. The program issuing this command should give the
   emulator adequate time to switch between hard drive image files.

Neither command provides any response or any other overt indication of success
or failure; programs should attempt to deduce the outcome in other ways.

(Note: the [IDEfile emulator](
http://john.ccac.rwth-aachen.de:8000/patrick/idefile.htm) uses a similar but
distinct "magic block" mechanism on block FFFFFD for access to its volume
table.)

## Block `FFFEFF`: Durable key/value store

Reads and writes to block `FFFEFF` provide access to a durable (i.e. retained
through reboots of the hard drive emulator) key/value store. Keys are 20 bytes
long; values are 512 bytes long. This store remains accessible no matter which
disk image file is currently in use by the emulator.

The facility presents as having a kind of volatile (that is, not retained
through system reboots) write-through cache where the 65,535 cache entries are
software controllable (as opposed to being controlled automatically, as with a
CPU cache for example). Cache keys are 16-bit values formed by the
concatenation of the retry count and the sparing threshold specified during a
ProFile read or a write. Reads can only request items from the cache, so
earlier writes must have directed the store to have loaded data there from the
durable key/value store. For writes, software must specify both a cache key and
the 20-byte store key; the data will be saved in both the cache and the durable
store automatically.

Operations:

- ProFile reads to `FFFEFF`: Retrieve the cache entry assocated with the 16-bit
  concatenation of the retry count and sparing threshold parameters specified
  in the read. The store key will be the first 20 bytes of the returned data;
  the value is the remaining 512 bytes.

- ProFile writes to `FFFEFF` with retry count and sparing threshold both set to
  $FF: Order the store to load key/value pairs into the cache. The data in the
  write has the following format:

      Byte      0: Number of key/value pairs to load (up to 24)

      Bytes   1-2: 2-byte key for the cache entry receiving the first value
      Bytes  3-22: 20-byte key of the value to load into that cache entry

      Bytes 23-24: 2-byte key for the cache entry receiving the second value
      Bytes 25-44: 20-byte key of the value to load into that cache entry

  And so on.

- ProFile writes to `FFFEFF` with any other retry count and sparing threshold
  parameters: Write data to the cache entry specified by the parameters and to
  the key/value store. The store key is the first 20 bytes of the data, and the
  value is the remaining 512 bytes.

From a logical perspective, any store keys not yet associated with any data are
paired with 512 $00 bytes, and any cache keys not yet associated with any data
are associated with 532 $00 bytes (in other words, an all-$00 20-byte key and
512 bytes of all-$00 data).

## Block `FFFEFE`: Filesystem operations

Reads and writes to this block enable some basic filesystem operations.  For
safety, operations may be limited to files with a particular suffix.

Operations:

- ProFile reads to `FFFEFE`: Retrieve information about a file in the current
  working directory. The emulator maintains a list of files (usually limited
  to those with a specific suffix, like ".image"), and a read obtains
  information about the n'th file in the list, where n is the 16-bit
  concatenation of the read's retry count and sparing threshold parameters.
  The contents of the 532-byte reply are:

      Bytes    0-3: Nonce
      Bytes    4-5: Number of files in the directory (suffix-limited)

      Bytes   6-19: YYYYMMDDHHMMSS ASCII last-modified time for the file
      Bytes  20-29: 10-character ASCII right-justified space-padded file size
      Bytes 30-275: Reserved, unused for now
      Bytes 276-??: Filename (length varies---up to 255 characters long)

         Remainder: $00 bytes, so the filename is null-terminated.
                    (There is always room for at least one null terminator.)

  By counting through values of n in the ProFile read parameters, programs
  that talk to the emulator can download a complete directory listing to
  present to the user. Programs that do this should save the nonce value at the
  beginning of one of the replies, which will change if and only if the contents
  of the current working directory change: as long as the nonce stays the same,
  the program will not need to download a new directory listing.

  (This strategy will not notice changes to file metadata like last-modified
  times or file sizes; the program will need to download a complete listing
  again if it's important to keep that data up-to-date.)

  If the program specifies an n greater than or equal to the number of
  (suffix-limited) files in the directory, the reply will list an empty 0-byte
  file with a length-0 filename.

- ProFile writes to `FFFEFE`: Order the Cameo/Aphid to perform a filesystem
  operation in the current working directory, or change some aspect of the
  behaviour of the "magic block". Here, the 16-bit concatenation of the write's
  retry count and sparing threshold parameters direct which operation to
  perform, and the data contents are the parameters. Excess space in the
  parameter data may be padded arbitrarily.

  For readability, the 16-bit command is usually made of ASCII characters.
  Commands are:

  - 'cp': copy a file. Parameters are a null-terminated source filename and a
    null-terminated destination filename immediately following. There must be
    no existing file at the destination.

  - 'mv': move a file. Parameters are a null-terminated source filename and a
    null-terminated destination filename immediately following. There must be
    no existing file at the destination.

  - 'mk': create a new disk image. The only parameter is a null-terminated
    filename for the new image. There must be no existing file by that name.

  - 'mx': create a new disk image, extended. Parameters are a null-terminated
    numeric size string and a null-terminated filename for the new image
    immediately following. There must be no existing file by that name.

  - 'rm': remove a file. The only parameter is the null-terminated name of
    the file to remove.

  - 'sx': set the file suffix to the one null-terminated parameter. The
    emulator will only list or operate on files that end with this suffix. (For
    file extensions like '.image', you must include the '.' character.) It is
    valid to specify an empty suffix.

  The emulator may refuse to carry out any of these operations for any reason.
  Furthermore, no feedback is returned about whethere an operation has been
  successful. For any operation that modifies the filesystem, one workaround
  is to perform a read and see whether the nonce has changed.

Filenames are sent to and from the emulator in the ISO-8859-1 (Latin-1)
character encoding.

## Block `FFFEFD`: Emulator status

Reads of this block retrieve basic system status information from the emulator.
The format in use is a good fit for emulators that incorporate Unix-like
operating systems (like Cameo/Aphid does) but may not be as useful for other 
implementations.

   Bytes   0-9: DDDDHHMMSS ASCII uptime; days right-justified space padded
   Bytes 10-24: ASCII right-aligned space-padded filesystem bytes free
   Bytes 25-31: ASCII null-terminated 1-minute load average
   Bytes 32-38: ASCII null-terminated 5-minute load average
   Bytes 39-45: ASCII null-terminated 15-minute load average
   Bytes 46-50: ASCII null-terminated number of processes running
   Bytes 51-55: ASCII null-terminated number of total processes

## Block `FFFEFC`: Selector rescue

This block provides read-only access to disk images of the Selector program
that are kept separate from hard drive image data stored on a Cameo/Aphid hard
drive emulator. It is impossible for any Apple connected to a Cameo/Aphid
device to alter or damage these disk images.

Additionally, one particular read of this block will replace the
`profile.image` file that Cameo/Aphid uses on power-on with an image that
contains the Selector program. This facility makes it easier to recover from
accidentally overwriting the Selector, which is not all that difficult to do by
accident. For details on practical ways to invoke this recovery procedure by
hand, refer to the [appropriate section of the Selector manual](
MANUAL.md#oops-i-damaged-or-deleted-the-selector).

Operations:

- ProFile reads to $FFFEFC: have effects that depend on the 16-bit concatenation
  of the read's retry count and sparing threshold parameters. These are:

  - $FFFF: copy the contents of a ProFile drive image containing the Selector
    program to `profile.image` in the current working directory, then trigger
    the start of a new emulation session using `profile.image` as the current
    hard drive image. If a file called `profile.image` already exists, it will
    be renamed to `profile.backup-X.image`, where `X` is the first number
    counting up from 0 that yields an unused filename. The block contents
    retrieved by this read are unspecified.

  - $0XXX: retrieve the $XXXth 532-byte block of a ProFile drive image
    containing the Selector program, in a format suitable for use with a
    Cameo/Aphid device; or, if the drive image is less than ($XXX - 1) * 532
    bytes long, retrieve a block of 532 $00 bytes.

  - $1XXX: retrieve the $XXXth 532-byte block of a DC42-format 400K disk image
    containing the Selector program, suitable for installation on a 400K 3.5"
    diskette or for use with the Floppy Emu floppy drive emulator; or, if the
    disk image is less than ($XXX - 1) * 532 bytes long, retrieve a block of
    532 $00 bytes.

  - $2XXX: retrieve the $XXXth 532-byte block of a DC42-format Twiggy disk image
    containing the Selector program, suitable for installation on a Twiggy
    diskette; or, if the disk image is less than ($XXX - 1) * 532 bytes long,
    retrieve a block of 532 $00 bytes.

- ProFile writes to $FFFEFC: do nothing at all.

-- _[Tom Stepleton](mailto:stepleton@gmail.com), 28 March 2021, London_

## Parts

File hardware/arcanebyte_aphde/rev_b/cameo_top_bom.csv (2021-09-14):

Comment | Designator | Footprint | LCSC Part #
10K | R2 R3 R14 R17 R18 R19 R20 R21 R22 R23 R24 R25 R26 R27 R28 R29 R30 R31 R32 R33 R34 R35 R36 R37 R38 R39 | R0603
120 | R4 | R0603
240k | R1 | R0603
BSS138 | Q1 Q2 Q3 Q4 Q5 Q6 Q7 Q8 Q9 Q10 Q11 Q13 Q14 | SOT95P240X111-3N
RED | D1 | LED-0603 | C72044

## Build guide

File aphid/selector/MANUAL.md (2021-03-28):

# Cameo/Aphid Selector

The Selector running on a Lisa 1 The Selector in real life

The Cameo/Aphid drive image selector program ("the Selector" for short) is a
program for Apple Lisa computers that controls a [Cameo/Aphid ProFile hard
drive emulator](https://github.com/stepleton/cameo/tree/master/aphid). Most
Selector users will use the Selector to create, manange, and boot hard drive
images that belong to a catalogue of hard drive images on their Cameo/Aphid
devices.

The Selector is a standalone program, meaning it does not run on top of an
operating system. It can be loaded and run from a hard drive or a floppy drive
(or an emulator of either). When it starts, depending on configuration, it can
present an interactive catalogue of hard drive images (shown above), or it can
automatically select and boot from one of the images.

## Table of contents

* [System requirements](#system-requirements)
* [User interface notes](#user-interface-notes)
  - [A working keyboard is needed for interactive use](#a-working-keyboard-is-needed-for-interactive-use)
  - [Accessibility](#accessibility)
  - [Screensaver](#screensaver)
* [Oops, I damaged or deleted the Selector](#oops-i-damaged-or-deleted-the-selector)
* [Main interactive interface and menu options](#main-interactive-interface-and-menu-options)
  - [B(oot and S(elect](#boot-and-select)
  - [N(ew](#new)
  - [C(opy](#copy)
  - [R(ename](#rename)
  - [D(elete](#delete)
  - [A(utoboot toggle](#autoboot-toggle)
  - [M(oniker](#moniker)
  - [K(ey/value](#keyvalue)
  - [P(ort](#port)
  - [Q(uit](#quit)
* [Autobooting](#autobooting)
* [Scripting](#scripting)
* [Potential improvements](#potential-improvements)
* [Acknowledgements](#acknowledgements)
* [Revision history](#revision-history)

## System requirements

The Selector is designed to run on any Apple Lisa computer, but a Cameo/Aphid
hard drive emulator (or a compatible device) must be connected to one of its
parallel ports in order for it to do anything useful. The emulator may be
connected to any parallel port, including ports on 2-port parallel expansion
cards. The Selector will not work on computers with Macintosh XL screen
modifications, nor on computers with most other modifications that would make
it impossible for the computer to run the Lisa Office System.

The Selector only works with Cameo/Aphid hard drive emulators running the
Cameo/Aphid software current to February 2021 or later.

Emulator designers who are interested in making Selector-compatible ProFile
emulators can find details of how the Selector controls the Cameo/Aphid in [the
Protocol document](PROTOCOL.md).

## User interface notes

### A working keyboard is needed for interactive use

The Selector uses a text-based user interface, and you control the Selector
entirely with the keyboard. A working keyboard is therefore necessary to use
the Selector in an interactive way. The Selector does not require a working
keyboard if it is configured to select and boot from one of the hard drive
images automatically, as this process does not require any user input.

### Accessibility

The Selector has poor accessibility for people with certain kinds of visual
impairments. Other shortcomings may exist.

If you are having trouble using the Selector due to any of its accessibility
limitations, please [contact me via email](mailto:stepleton@gmail.com).

### Screensaver

The Selector has a built-in screensaver that displays a scrolling texture on
the screen. At certain places where the Selector expects user input, it will
automatically start the screensaver after around 90 seconds of waiting. You can
exit the screensaver by pressing any key.

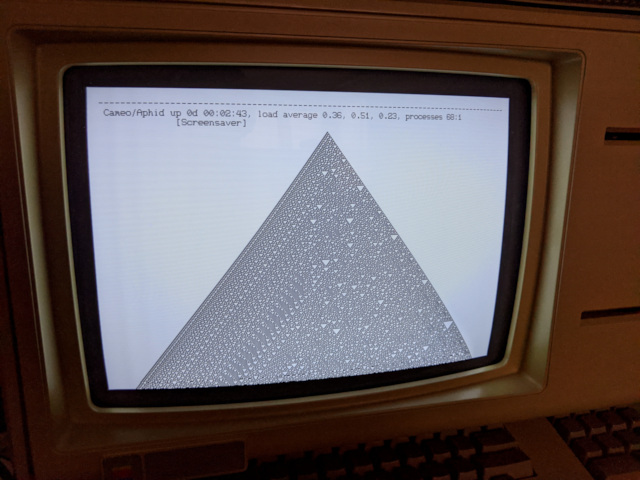
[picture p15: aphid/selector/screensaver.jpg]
The Selector's screensaver starting up


The Selector is not capable of activating the screensaver in all situations
where it expects user input --- for example, input textboxes like those used to
collect filenames cannot be interrupted by the screensaver. Still, it's hoped
that the screensaver works now in the situations where the Selector is most
likely to be left unattended. Don't rely on the Selector's screensaver alone to
protect your Lisa's CRT from burn-in.

The screensaver's scrolling texture is based on the [Rule 30](
https://en.wikipedia.org/wiki/Rule_30) elementary finite automaton, which was
discovered around the time the Lisa was developed. It expands from a single
pixel and widens to stretch across the screen.

## Oops, I damaged or deleted the Selector

Even though it's used to select and manage hard drive image files, the Selector
program itself is also loaded from an ordinary image file. This file is usually
`profile.image`, the drive image that the emulator uses by default when it is
powered on. There is nothing special about this drive image, and so it's
possible to overwrite or damage the Selector program data by doing relatively
ordinary things to a Cameo/Aphid, like installing an operating system or
initialising a filesystem ("formatting the drive", "erasing the disk").

If you find that you have damaged or modified your Selector hard drive image
and you wish to restore it, there are a few things you can do.

#### Restoring the Selector with a modern computer

1. Download [selector.image.zip](selector.image.zip) onto a modern computer
   and unzip it, giving you the replacement Selector drive image file
   `selector.image`.

2. With the Cameo/Aphid off, remove the microSD card and plug it into the
   modern computer. Find and open the microSD card partition called
   `CAMEO_APHID`.  If you don't want to lose the hard drive image that you
   modified by accident, you can use it under a different name: just rename
   `profile.image` to something else that ends in `.image`.

3. Rename the `selector.image` file you unzipped in step 1 to `profile.image`
   and copy it onto the `CAMEO_APHID` partition.

4. Eject the microSD card from your computer and plug it back into the
   Cameo/Aphid, which is now ready to be used as normal.

#### Restoring the Selector with your Apple Lisa

**This procedure will only work if the Cameo/Aphid is attached to the Lisa's
built-in parallel port.** This is the port next to the mouse connector on Lisa
1 and Lisa 2/5 systems, or the Widget ribbon cable inside Lisa 2/10 systems.

1. Reboot the Lisa into Service Mode. If you're not sure how to do this,
   [refer here for instructions](
   https://lisafaq.sunder.net/lisafaq-hw-rom_servicemode.html).

2. Type in the following two lines to enter a short program into the Lisa's
   memory:

   ```
   2900 223C 00FF FEFC 227C 00FE 0090 50C2 50C3↵
   2910 50C4 4ED1↵
   ```

   where `↵` means to press the Return or ↵ key. You must include all of the
   spaces shown. Note that the `2` at the start of each line will not appear
   on the screen: it selects the "SET MEMORY" function from the "SERVICE MODE"
   menu.

3. To check that you've entered the program correctly, type `1900 20↵`.
   Verify that the screen displays something like the following:

   ```
   223C 00FF FEFC 227C 00FE 0090 50C2 50C3
   50C4 4ED1 xxxx xxxx xxxx xxxx xxxx xxxx
   ```

   where it doesn't matter what is displayed at the locations marked with
   `xxxx`; that is, only the first two words of the second line matter. If
   you see anything that doesn't match, go back to Step 2 and continue from
   there.

4. Finally, execute the program by typing `3900↵`.

The Lisa should appear to restart immediately, and if it starts up from the
internal port, it should load the Selector. You should observe that the drive
image that was previously called `profile.image` will have been renamed
`profile.backup-0.image`, or if there was already a file by that name,
`profile.backup-1.image`, and so on.

## Main interactive interface and menu options

The main interactive interface for the Selector presents a screen that looks
like this:

```

 [No Name] Command: B(oot, S(elect, N(ew, C(opy, R(ename, D(elete, ? [1.0]

  Filename                                                    1,234,567,890 bytes free
 --------------------------------------------------------------------------------------
  Hard_drive_image_01.image                                                        10M
  Hard_drive_image_02.image                                                         5M
  Hard_drive_image_03.image                                                       256M
  Hard_drive_images_can_have_arbitrary_names.image                                 32M
  Hence_these_filenames_are_just_examples.image                                     5M
  profile.image                                                                     5M

 --------------------------------------------------------------------------------------
  Cameo/Aphid up 1d 23:34:45, load average 0.43, 0.32, 0.21, processes 67:1

```

A catalogue of drive image files present on the Cameo/Aphid occupies most of
the screen. Within the catalogue, one of the image files will be selected at
all times, with its filename highlighted in inverse video. You can change the
selection by using the arrow keys (`[▲]` or `[▼]`) or the 8 and 2 keys on the
keypad to move the selection up and down respectively.

The top of the screen shows a partial menu of keyboard commands:
```
 [No Name] Command: B(oot, S(elect, N(ew, C(opy, R(ename, D(elete, ? [1.0]
```
The bracket `(` indicates that the first letter of the command activates the
command, thus the `C` key will start the Copy command. Also shown here are the
version number of the Selector software (the `1.0` in square brackets at right)
and the "moniker" for this Cameo/Aphid (the `No Name` in square brackets at
left). A moniker is a name given to a Cameo/Aphid for identification purposes:
more precisely, it's a name given to a microSD card containing an installation
of the Cameo/Aphid system software, since microSD cards can be moved between
Cameo/Aphid devices, and all the configuration and hard drive image files on
the cards will move with them.

Typing a `?` will change this top line to show an additional menu of keyboard
commands:
```
 [No Name] Command: A(utoboot toggle, M(oniker, K(ey/value, P(ort, Q(uit
```
Typing `?` toggles between displaying both partial menus, so typing it again
here will result in the display of the first menu. Although only some of the
keyboard commands are shown on the screen at any moment, all commands are
available in the main interface regardless of what can be seen; even if the menu
just above is displayed, you can still use the `C` key to execute the Copy
command.

Beneath the menu and above the catalogue, on the right side of the screen, the
free space remaining for drive images on the Cameo/Aphid appears. It is shown as
`1,234,567,890 bytes free` in the screen depiction above. (Available space may
be much smaller than the size of your microSD card, since it depends on how much
of your card has been reserved for storing hard drive images. For [default
installations of the Cameo/Aphid system software](
https://github.com/stepleton/cameo/tree/master/aphid#software-installation),
this amounts to around 500 MiB, still enough room for lots of ProFile hard drive
images.)

Basic runtime information about the Cameo/Aphid system appears beneath the
catalogue. This information resembles the information printed by the [`uptime`
command](https://man7.org/linux/man-pages/man1/uptime.1.html) on Unix-like
operating systems, except it shows the number of running and total processes
instead of the number of logged-in users. This information updates around once
every two seconds. It serves little purpose except to look "geeky" and to
demonstrate that the Cameo/Aphid is operating and responsive.

Finally, while the catalogue is displayed, you can cause the Lisa to eject all
floppy disks and power down by pressing the power button.

The rest of this section describes all of the keyboard commands.

### B(oot and S(elect

The **Select** command causes the Cameo/Aphid to switch its current hard drive
image to the one selected in the catalogue display. The **Boot** command does
the same, then attempts to boot the Lisa from that hard drive image after
ejecting any inserted floppy disks.

When the Cameo/Aphid switches to a different hard drive image, this means that
all reads and writes to the emulated hard drive will access data from the
new hard drive image instead of the image the Cameo/Aphid was serving
previously.

On most Cameo/Aphid installations, a hard drive image change will persist until
the Selector changes the image again or until the Cameo/Aphid is restarted.
Rebooting or turning off the Lisa has no effect on the Cameo/Aphid --- it merely
appears to the emulator that the computer has stopped sending commands for a
little while --- so if you wish to return to the Selector, it's typically
necessary to shut down and restart the Cameo/Aphid itself or to boot the
Selector from a floppy disk.

### N(ew

The **New** command is for creating new ProFile hard drive images. It presents
this interface:
```

 { New image }

 New filename: [Untitled.image                                                         ]

 Return (↵) to proceed, Clear (⌧) to cancel.

```
You can modify the new filename with the keyboard in a conventional way, but
the `.image` suffix cannot be changed. After you press Return, the Selector
will ask what size the new drive image should be with this prompt:
```
 What size? (1) 5M ProFile, (2) 10M ProFile, (3) 16M, (4) 32M, (5) 256M, or C(ancel
```
Note that some Lisa operating systems are only compatible with a few of these
options: in general, the "non-ProFile" sizes will only work with certain
versions of MacWorks (larger sizes require newer MacWorks and Classic MacOS
versions). Once you choose, the Selector will check to make sure that the
filename isn't already in use by another image file, then issue an image file
creation command to the Cameo/Aphid.

Even if these steps complete successfully, the Cameo/Aphid may refuse to
generate the new drive image for one reason or another: perhaps the name you've
specified contains illegal characters like '/', or maybe there's not enough
empty space left to hold a new hard drive image. Also, with slower microSD
cards, it can take so long to create a larger drive image that the Selector
will assume that the operation has failed, even when it ultimately succeeds.
Either way, browse the drive image catalogue to be certain of whether your new
hard drive image has been created.

### C(opy

The **Copy** command is for duplicating ProFile hard drive images. It presents
this interface:
```

 { Copy image }

    Copy from:  Xenix_3.0_rel1.image
 New filename: [Xenix_3.0_rel1.image                                                   ]

 Return (↵) to proceed, Clear (⌧) to cancel.

```
The "Copy from:" filename was the highlighted catalogue filename when the Copy
command was executed at the main interface by pressing the `C` key.

You can modify the filename for the duplicate image in a conventional way, but
the `.image` suffix cannot be changed. You must specify a novel filename in
order for the duplication to work, so some modification is required. After you
press Return, the Selector will check to make sure that the filename isn't
already in use by another image file, then issue a duplication command to the
Cameo/Aphid.

Even if these steps complete successfully, the Cameo/Aphid may refuse to
generate a duplicate drive image for one reason or another: perhaps the name
you've specified contains illegal characters like '/', or maybe there's not
enough empty space left to hold a new hard drive image. Also, with slower
microSD cards, it can take so long to copy a larger drive image that the
Selector will assume that the operation has failed, even when it ultimately
succeeds.  Either way, browse the drive image catalogue to be certain of
whether the duplicate hard drive image has been created.

### R(ename

The **Rename** command is for renaming ProFile hard drive images. It presents
this interface:
```

 { Rename image }

 Old filename:  GEMDOS_Experimental.image
 New filename: [GEMDOS_Experimental.image                                              ]

 Return (↵) to proceed, Clear (⌧) to cancel.

```
The "Old filename:" was the highlighted catalogue filename when the Rename
command was executed at the main interface by pressing the `R` key.

You can modify the new filename for the image in a conventional way, but the
`.image` suffix cannot be changed. You must specify a novel filename in order
for the renaming to work, so some modification is required. After you press
Return, the Selector will check to make sure that the filename isn't already in
use by another image file, then issue a renaming command to the Cameo/Aphid.

Even if these steps complete successfully, the Cameo/Aphid may refuse to rename
the drive image for one reason or another: perhaps the name you've specified
contains illegal characters like '/'. Browse the drive image catalogue to be
certain that the hard drive image has been renamed.

The Cameo/Aphid will not rename the drive image file called `profile.image`,
since this is the drive image that the emulator uses by default when it is
powered on. Usually this drive image contains the Selector itself.

### D(elete

The **Delete** command is for deleting ProFile hard drive images. It presents
this interface:
```

 { Delete image }

   Image file: MacWorks_Plus.image

 This operation CANNOT BE UNDONE!
 Return (↵) to proceed, Clear (⌧) to cancel.

```
The "Image file:" filename was the highlighted catalogue filename when the
Delete command was executed at the main interface by pressing the `D` key.

After you press Return, the Selector will check to make sure that the filename
is present in the catalogue (it's unlikely that this will fail), then issue a
deletion command to the Cameo/Aphid.

Even if these steps complete successfully, the Cameo/Aphid may refuse to
delete the drive image for one reason or another: for example, it won't delete
the image file called `profile.image`, since this is the drive image that the
emulator uses by default when it is powered on. (Usually this drive image
contains the Selector itself.) Browse the drive image catalogue to be certain
that the hard drive image has been deleted.

### A(utoboot toggle

The **Autoboot toggle** command lets you enable, disable, or configure the
Selector's ability to "autoboot" from one of the disk images, which means
that shortly after the Selector is first started, it will carry out the
operations of the **Boot** command on that disk image without any input from
the user. See the [Autobooting](#autobooting) section for more details.

If autoboot is disabled, the `A` key will result in this interface:
```

 { Autoboot setup }

   Pascal_Workshop_3.9.image

 S)et autoboot to this file, or C)ancel?

```
If autoboot is already enabled, the list of options is
```
 T)urn off autoboot, S)et autoboot to this file, or C)ancel?
```
Either way, the displayed filename was the highlighted catalogue filename when
the Autoboot toggle command was executed at the main interface.

Typing `T` here will disable autoboot, which means that on boot, the Selector
will present the main interactive interface. Typing `S` will enable autoboot for
the drive image file shown, but not before giving the user a chance to enter an
autoboot password:
```
 Password for interrupting autoboot? Leave blank for none: [        ]

 Return (↵) to proceed, Clear (⌧) to cancel.
```
The autoboot password mechanism is described in the [Autobooting](#autobooting)
section. Cancelling here will mean that the Selector makes no changes to its
existing autoboot configuration; a password entered here will mean that the
user has to supply that password on Selector start-up in order to cancel the
autoboot process. An empty password (achieved by pressing Return or ↵
straightaway) allows the user to cancel the autoboot process without supplying
a password.

### M(oniker

The **Moniker** command lets you change the "moniker" associated with the
microSD card in your Cameo/Aphid (and therefore with the collection of drive
image files and the Selector configuration on that microSD card). A moniker is
a name used for identification purposes, and it may be useful if you have
multiple Cameo/Aphid devices or use more than one microSD card in your
Cameo/Aphid. The moniker may also be useful for advanced scripts (see the
[Scripting](#scripting) section for details).

The Moniker command presents this interface:
```

 { Change moniker }

 Moniker: [No Name        ]

 Return (↵) to proceed, Clear (⌧) to cancel.

```
A moniker may be up to 15 characters long. It cannot be empty.

### K(ey/value

The **Key/value** command is a "power user" command that allows you to edit
entries in the Cameo/Aphid's durable key/value store. The [description of the
key/value store in the protocol description document](
PROTOCOL.md#block-fffeff-durable-keyvalue-store) clarifies the meanings of
the fields in the Key/value command's interface:
```

 { Key/value store editor }

       Key: [Some arbitrary key  ]
 Cache key: [Sk]

 Edit which row (1-8), W(rite to the key/value store, or C(ancel?

 1: 000-03F [Here are the 512 bytes of data that are associated with the key ]
 2: 040-07F ["Some arbitrary key  " in the Cameo/Aphid key/value store. The d]
 3: 080-0BF [ark rectangles represent $00 bytes.█████████████████████████████]
 4: 0C0-0FF [████████████████████████████████████████████████████████████████]
 5: 100-13F [████████████████████████████████████████████████████████████████]
 6: 140-17F [████████████████████████████████████████████████████████████████]
 7: 180-1BF [████████████████████████████████████████████████████████████████]
 8: 1C0-1FF [████████████████████████████████████████████████████████████████]

```
The editor requests the key and cache key for the entry you wish to edit
before it reads and presents the value data for the entry in the rows numbered
1 through 8. Editing capabilities are rudimentary, with each row allowing you
to modify 64-byte segments of the value data in a conventional way.

When you use the `W` key to tell the Selector to update the key/value store
entry, the Selector first asks if it should replace the final two bytes of the
value data with a computed checksum word:
```
 Replace bytes 1FE-1FF with a checksum before writing? (Y/N)
```
The Selector keeps configuration information under certain keys in the key/value
store. Most of this information must be accompanied by a valid checksum word in
order for the Selector to consider the data valid.

### P(ort

The **Port** command changes the parallel port in use by the Selector. By
changing parallel ports, you can use the Selector to control multiple
Cameo/Aphid devices connected to the same computer. This command presents this
interface:
```

 { Choose parallel port }

 Scanning for connected Cameo/Aphid devices... done.
 (1) Built-in parallel port: "My Moniker"
 (4) Lower port on expansion slot 2: "Other Moniker"
 (5) Upper port on expansion slot 2: "Moniker #3"

 Please select a parallel port by number.

```
As it prepares this menu, the Selector program scans all of the Lisa's parallel
ports. When it finds a port with a Cameo/Aphid device attached, it displays the
port as a menu item along with the Cameo/Aphid's moniker. The numbers that
select different parallel ports are not always contiguous because menu items
for ports without Cameo/Aphid devices connected to them are not shown.

Selecting a parallel port from the menu will return you to the main interactive
interface, with the drive image catalogue showing drive image files on the
Cameo/Aphid device connected to that port.

The Selector automatically executes the Port command immediately after start-up
if it is loaded from a device that isn't a Cameo/Aphid. The appearance of its
on-screen display has cosmetic differences to the example shown above in this
situation.

### Q(uit

The **Quit** command causes the Selector program to terminate and return control
of the computer to the Apple Lisa boot ROM.

## Autobooting

The Selector's "autoboot" mechanism allows the Selector to automatically switch
the hard drive image that the Cameo/Aphid is serving to the Lisa and then boot
from that hard drive image. This mechanism enables a style of working with the
Cameo/Aphid that resembles the use of an ordinary hard drive (turn on the
drive, turn on the Lisa, then boot from the hard drive without intervention)
whilst still allowing you to interrupt the process and use the Selector if you
choose.

With autoboot enabled, the Selector prints information like the following to the
screen prior to booting from the designated hard drive image:
```

 [Cameo/Aphid]
 Hard drive image manager v1.0
 Connecting to the boot drive: the built-in parallel port... OK
 Loading configuration into the key/value cache... OK
 Reading configuration... OK
 Reading key/value data from cache... OK

 (Any key to interrupt) Running autoboot program in 3...2...1...

 Updating the drive image catalogue... OK
 Checking that there is a drive image called blu.image... OK
 Changing the drive image to blu.image... OK
 Floppy eject... OK
 Booting from the built-in parallel port...

```
Most status messages shown are not very important when everything is working,
but they may help you troubleshoot if something goes wrong. Otherwise, the most
important item is the `3...2...1...` countdown, which takes a few seconds to
complete. During that time, you may interrupt the autoboot process by pressing
any key, which can take you to the main interactive interface. If the user has
specified an autoboot password, though, you will first have to enter the
password at a prompt that looks like this:
```
 Password: [        ]
```
and press Return or ↵. If the password you supply is incorrect, the autoboot
process will start over from the beginning, and you will have to interrupt the
countdown again in order to try a different password.

The autoboot mechanism is built on the Selector's rudimentary [scripting
capability](#scripting) and may be coerced into doing more sophisticated things
than booting a single hard drive image.

See the [Autoboot toggle](#autoboot-toggle) command description for information
on enabling and disabling autobooting.

## Scripting

The [autoboot mechanism](#autobooting) uses a rudimentary scripting capability
built into the Selector. When autobooting is enabled, a small script is written
to the key/value store that tells the Selector to perform all of the steps of
the autoboot process. For a hard drive image called `kazoo.image`, the script
would look like this:
```
ClogImag0Akazoo.image_EjctBootHalt
```
This script contains five commands: `Clog`, which means "update the drive image
catalogue"; `Imag`, meaning "switch to the following hard drive image"; `Ejct`,
"eject all floppy disks"; `Boot`, "boot from the hard drive image"; and `Halt`,
marking the end of the script. The terse "scripting language" is designed more
for the Selector's convenience than the user's, but it is at least possible to
use the [key/value editor](#keyvalue) to make more elaborate custom scripts.

Scripts are made of sequences of commands and their arguments. There is no
flow control, and any command that fails will cause the script to terminate.
All commands have four-byte names and must be "word-aligned" within the script:
that is, they must be positioned so that they begin on even-numbered bytes. This
explains the `_` character inside the example above: it's meaningless padding
between the end of the "kazoo.image" argument value and the `Boot` command.

Except for padding bytes, there is no spacing between script commands.

Here is a list of the commands that you can use in scripts. **Note that only
the `Clog`, `Imag`, `Ejct`, `Boot`, and `Halt` commands have been tested at
time of writing.**

* `Halt`: Immediately terminate the script. The Selector will interpret any
  script that reaches a `Halt` command as having completed successfully.

* `Scan`: Scan all parallel ports on the computer for attached Cameo/Aphid
  devices and update the drive catalogue. If you intend to use the `Name`
  command in an autoboot script, it will be necessary to execute this command
  first, since the Selector does not automatically scan for Cameo/Aphid devices
  when it first runs.

* `Name`: followed by a 2-digit hexadecimal number (e.g. `0C` for 12) and then
  a string argument of that many characters _plus one_ (e.g. `ThirteenChars`).
  If the string argument has an odd number of characters, you must follow it
  with a meaningless padding byte, e.g. `^`. (Complete example:
  `ThirteenChars^`)

  Search the drive image catalogue for a Cameo/Aphid device whose moniker is the
  same as the string argument, which means the drive image catalogue must be
  up-to-date (see the `Scan` command). If one is found, make that device's
  parallel port the Selector's current parallel port.

* `Home`: Make the parallel port hosting the Cameo/Aphid that was used for
  booting the Lisa the current parallel port. Will fail if the boot device was
  not a Cameo/Aphid (for example, if it was a floppy disk).

* `Ejct`: Tell all of the Lisa's floppy disk drives (i.e. both Twiggy drives on
  a Lisa 1; the 3.5" drive on a Lisa 2) to eject their disks.

* `Boot`: Boot the Lisa from the hard drive device on the Selector's current
  parallel port. If the hard drive device is a Cameo/Aphid, then whatever drive
  image is the current drive image on that device will be the drive image that
  the Cameo/Aphid serves during and after the boot process.

* `Clog`: Refresh the drive image catalogue. If you intend to use the `Imag`
  command in an autoboot script or after changing the current parallel port
  (via `Home` or `Name`), it will be necessary to execute this command first,
  since the `Imag` command will check to see whether a drive image file exists,
  and the Selector does not update the drive image catalogue automatically when
  it first runs or when it switches parallel ports.

* `Imag`: followed by a 2-digit hexadecimal number (e.g. `1A` for 26) and then
  a string argument of that many characters _plus one_ (e.g.
  `Workshop_(Pascal)_3.9.image`). If the string argument has an odd number of
  characters, you must follow it with a meaningless padding byte, e.g. `~`.
  (Complete example: `Imag1AWorkshop_(Pascal)_3.9.image~`)

  Tell the Cameo/Aphid device on the current parallel port to switch the current
  hard drive image to the specified file. Fails if the specified image doesn't
  exist in the catalogue, which means the catalogue must be up-to-date (see the
  `Clog` command). Use the `Ima!` command if you'd like to skip the catalogue
  check.

* `Ima!`: Same as the `Imag` command, except it doesn't check whether the
  specified drive image exists in the drive image catalogue.

* `Prnt`: followed by a 2-digit hexadecimal number (e.g. `0B` for 11) and then
  a string argument of that many characters _plus one_ (e.g. `Hello world!`).
  If the string argument has an odd number of characters, you must follow it
  with a meaningless padding byte, e.g. `+`. (Complete example:
  `Prnt0CHello Planet!+`)

  Print a string to the display. Does not print additional newlines or any other
  characters besides what you specify.

* `Read`: followed by the characters `01` and then a two-byte cache key (e.g.
  `Hi`).

  (This is an advanced command that requires a good understanding of the
  [key/value store](PROTOCOL.md#block-fffeff-durable-keyvalue-store) and, if
  used in scripts alongside the `Name` or `Home` commands, some caution about
  which Cameo/Aphid the Selector is communicating with.)

  Read a script from the cache of the key/value store in the Cameo/Aphid device
  on the current parallel port, then run it. Scripts are up to 510 bytes long
  (you don't have to use all that space) followed by a two-byte checksum word
  (see the [key/value editor](#keyvalue) editor documentation for more
  information about checksums).

  In order for the `Read` command to read a script by its two-byte cache key,
  the script must already be resident in the cache of the Cameo/Aphid's
  key/value store. Any Cameo/Aphid device that has been detected by the `Scan`
  command is guaranteed to have loaded these key/value store entries into the
  cache:

  - `Selector: script 00 ` (note trailing space) under cache key `Sa`. This is
    the script that the Selector will run on start-up if autobooting is enabled.
  - `Selector: script 01 ` (note trailing space) under cache key `Sb`.
  - `Selector: script 02 ` (note trailing space) under cache key `Sc`.
  - `Selector: script 03 ` (note trailing space) under cache key `Sd`.
  - And so on for `03` through `21` and cache keys `Se` through `Sv`
    respectively, giving 22 scripts accessible to the `Read` command on any
    Cameo/Aphid device.

A more elaborate autoboot script could use several of these commands to prepare
a Lisa with three Cameo/Aphid devices to host a "large scale" Xenix
installation with three ProFile hard drives. Imagine that the Cameo/Aphid
connected to the built-in parallel port is called "Alice", and that two more
Cameo/Aphid devices with the names "Bob" and "Carol" are connected to the
parallel ports on a 2-port parallel expansion card. This script
```
Scan
Name02Bob~ClogImag0EXenix_Usr.image~
Name04Carol~ClogImag13Xenix_UsrLocal.image
Name04Alice~ClogImag0FXenix_Root.image
EjctBootHalt
```
(where line breaks have been added for display purposes only) tells Bob, Carol,
and Alice to switch to the drive images `Xenix_Usr.image`,
`Xenix_UsrLocal.image`, and `Xenix_Root.image` respectively, then ejects any
floppy disks, then tells Alice to boot the Lisa from `Xenix_Root.image`. Note
placement of padding bytes where necessary, use of the `Clog` command prior to
`Imag`, and the final `Halt` command for consistency's sake, even though the
`Boot` command is unlikely to ever finish running (instead, presumably, it will
boot the Xenix operating system, which will evict the Selector from memory
altogether).

Most script commands print information to the display, allowing you to monitor
their progress (if you can read fast enough) and to know where an error has
occurred if trouble is encountered.

## Potential improvements

#### 1. It should be possible to copy drive images between two Cameo/Aphids

#### 2. It should be possible to transfer drive images over the serial port

It's possible that the best place for both of these features is a separate
computer program. When the Selector boots, the entire Selector program is
loaded into memory, and bundling in more features mean longer load times.

#### 3. There should be a way to run scripts besides the autoboot mechanism

At present, the only way to run a custom script is to enable the autoboot
mechanism and then manually edit the autoboot script in the key/value editor.
Custom scripts may be useful for purposes besides autobooting, and it may be
useful to be able to invoke a custom script manually.

#### 4. The Selector should be able to install itself onto boot media

[The BLU program](http://sigmasevensystems.com/BLU.html) can install itself
onto hard drives and floppy disks. It may not be so difficult for the Selector
to do something similar.

## Acknowledgements

It would not have been possible for me to create the Cameo/Aphid hard drive
image selector without the help of the following people and resources:

- [Dr. Patrick Schäfer](http://john.ccac.rwth-aachen.de:8000/patrick/index.htm),
  whose [UsbWidEx](http://john.ccac.rwth-aachen.de:8000/patrick/UsbWidEx.htm)
  device was invaluable to early development of the Cameo/Aphid plugin system.
- [bitsavers.org](http://bitsavers.org)'s archived technical documentation.
- The [EASy68K-asm](https://github.com/rayarachelian/EASy68K-asm) standalone
  assembler 
- The [LisaEm](http://lisa.sunder.net) emulator by Ray Arachelian.
- The [Floppy Emu](http://www.bigmessowires.com/floppy-emu/) floppy drive
  emulator.
- The [BLU](http://sigmasevensystems.com/BLU.html) utility by James MacPhail
  and Ray Arachelian.
- The entire [LisaList2](https://lisalist2.com/) community.

## Revision history

17 January 2021: Initial release.
(Tom Stepleton, [stepleton@gmail.com](mailto:stepleton@gmail.com), London)

24 January 2021: 0.6 release, adding the S(elect command.
(Tom Stepleton)

30 January 2021: 0.7 release, adding a screensaver.
(Tom Stepleton)

16 February 2021: 0.8 release, status printing bugfix.
(Tom Stepleton)

28 February 2021: 0.9 release, image creation size option.
(Tom Stepleton)

28 March 2021: 1.0 release, power button, floppy eject, autoboot password.
(Tom Stepleton)

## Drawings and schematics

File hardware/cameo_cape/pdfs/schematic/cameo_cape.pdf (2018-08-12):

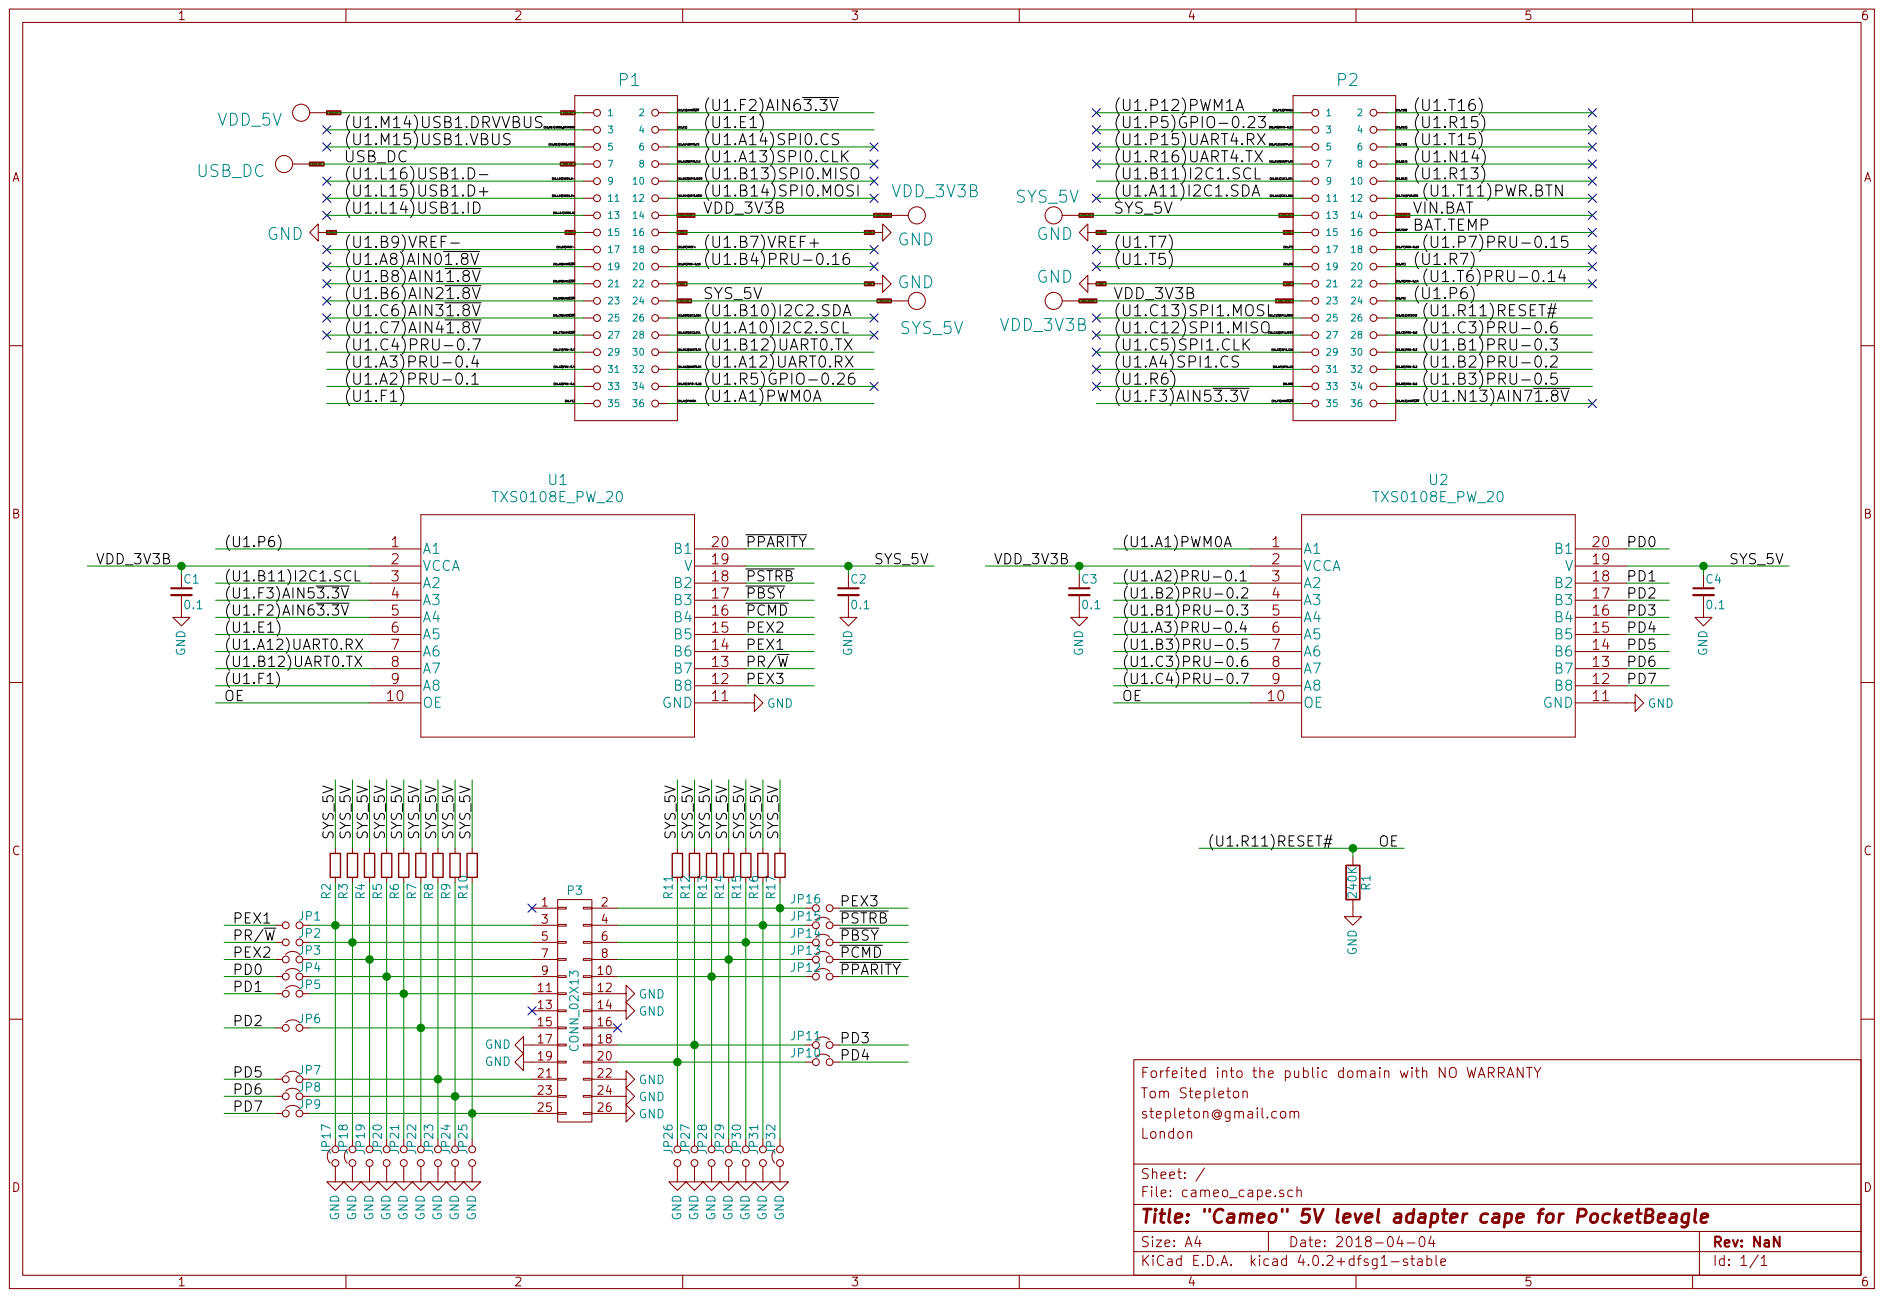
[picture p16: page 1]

Forfeited into the public domain with NO WARRANTY
Tom Stepleton
stepleton@gmail.com
File: cameo_cape.sch Sheet: / London

Id: 1/1 Title: "Cameo" 5V level adapter cape for PocketBeagle

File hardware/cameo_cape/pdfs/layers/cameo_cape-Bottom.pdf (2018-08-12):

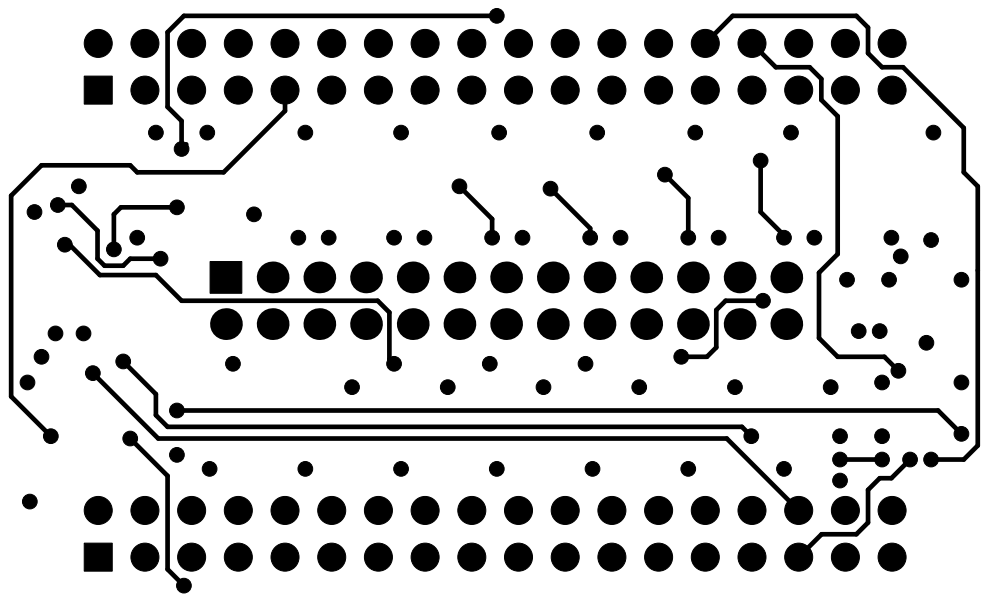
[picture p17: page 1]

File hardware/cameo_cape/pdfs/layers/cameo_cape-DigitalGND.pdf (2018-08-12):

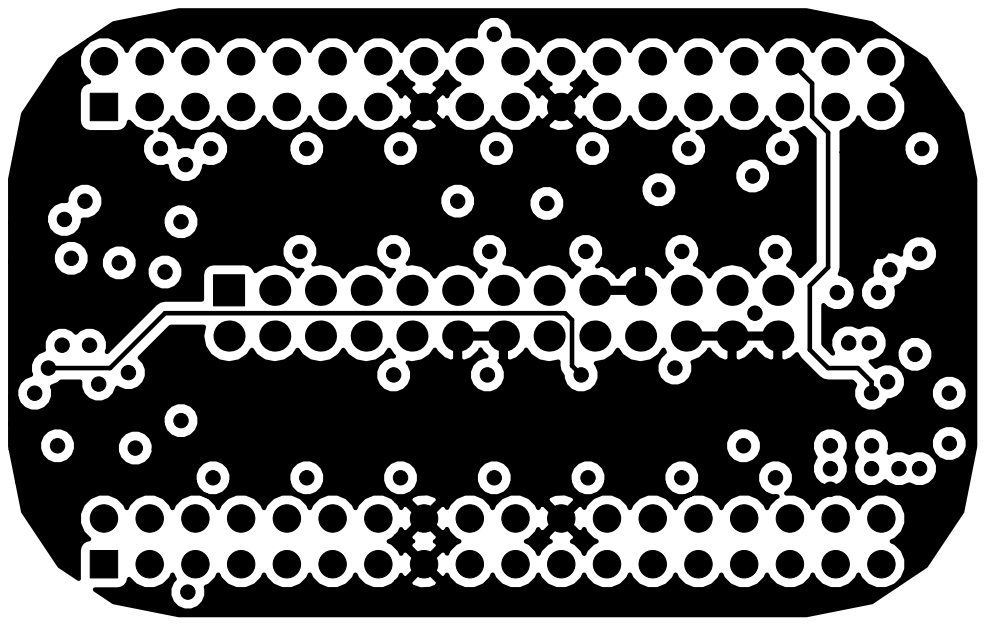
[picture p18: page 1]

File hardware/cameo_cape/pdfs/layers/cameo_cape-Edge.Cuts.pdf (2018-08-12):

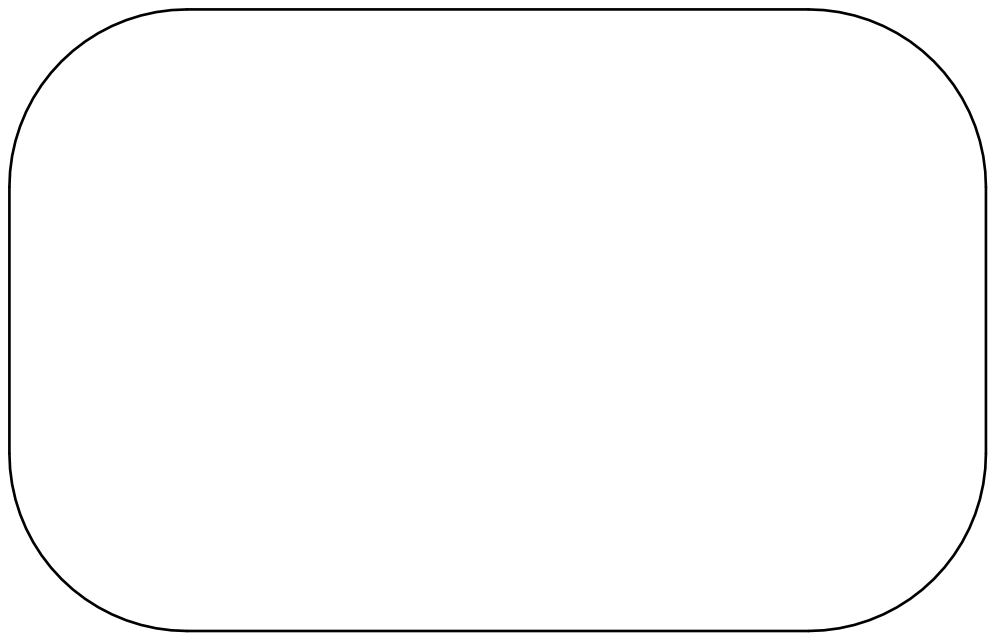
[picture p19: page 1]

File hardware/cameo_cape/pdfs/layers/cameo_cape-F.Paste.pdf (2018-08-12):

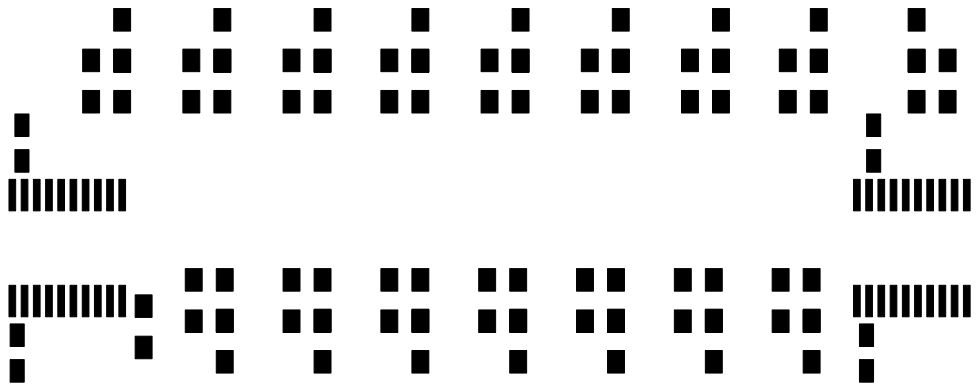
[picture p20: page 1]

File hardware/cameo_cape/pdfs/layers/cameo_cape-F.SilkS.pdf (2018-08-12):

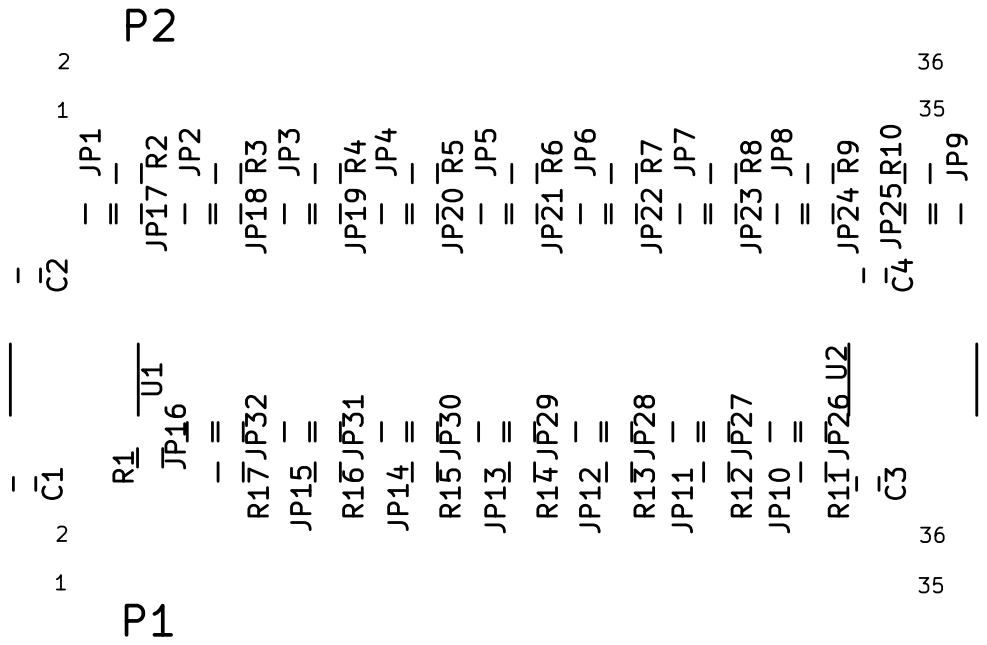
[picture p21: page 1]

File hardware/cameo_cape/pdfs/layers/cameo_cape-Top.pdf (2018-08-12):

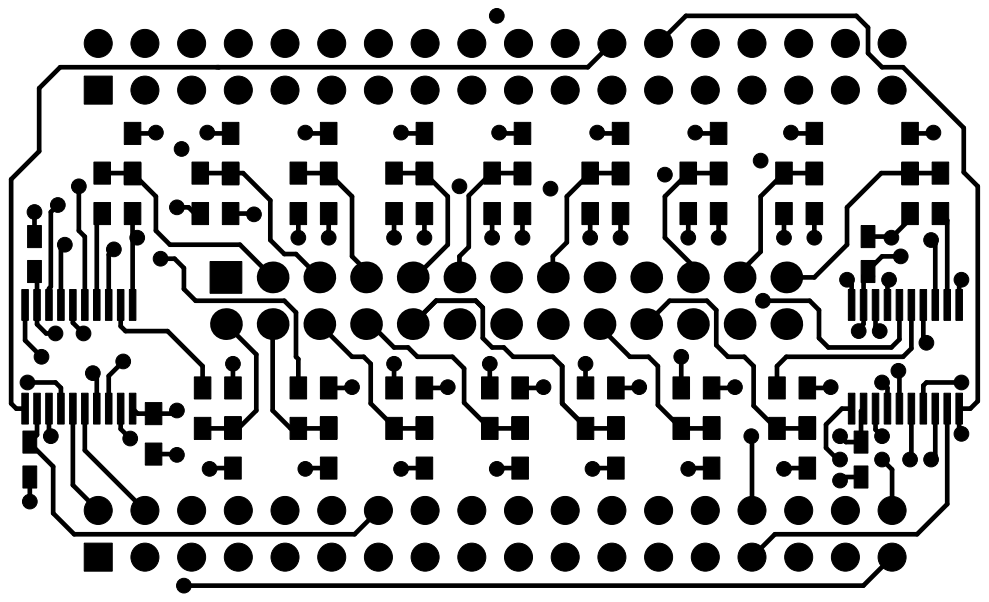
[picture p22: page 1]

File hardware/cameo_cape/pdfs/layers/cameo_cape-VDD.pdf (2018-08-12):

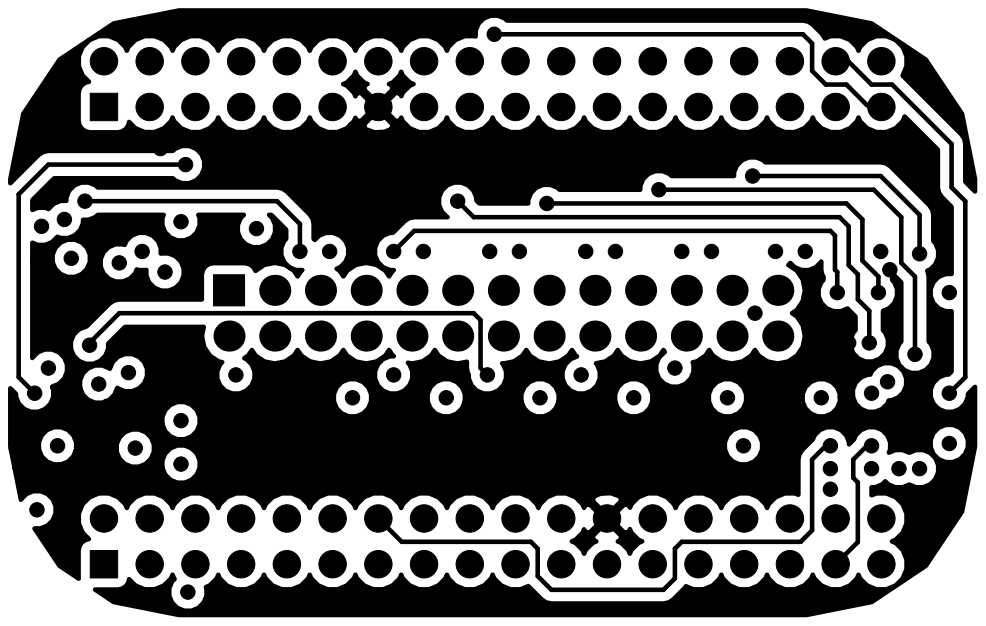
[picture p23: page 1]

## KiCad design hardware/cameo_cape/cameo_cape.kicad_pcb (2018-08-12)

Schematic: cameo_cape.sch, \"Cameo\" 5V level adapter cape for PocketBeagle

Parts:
C1, C2, C3, C4: 0.1; C_0603_HandSoldering
JP1, JP2, JP16, JP19, JP20, JP21, JP22, JP23, JP24, JP25, JP26, JP27, JP28, JP29, JP30, JP31: Jumper_NO_Small; R_0603_HandSoldering
JP3, JP4, JP5, JP6, JP7, JP8, JP9, JP10, JP11, JP12, JP13, JP14, JP15, JP17, JP18, JP32: Jumper_NC_Small; R_0603_HandSoldering
P1, P2: TH-2X18-(35MIL-DIA)-W_O-SILK
P3: CONN_02X13; Pin_Header_Straight_2x13
R1: 240K; R_0603_HandSoldering
R2, R3, R4, R5, R6, R7, R8, R9, R10, R11, R12, R13, R14, R15, R16, R17: R_Small; R_0603_HandSoldering
U1, U2: TXS0108E_PW_20; TXS0108EPWR

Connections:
/(U1.A1)PWM0A: P1.36, U2.1 (A1)
/(U1.A2)PRU-0.1: P1.33, U2.3 (A2)
/(U1.A3)PRU-0.4: P1.31, U2.6 (A5)
/(U1.A4)SPI1.CS: P2.31
/(U1.A8)AIN0~1.8V: P1.19
/(U1.A10)I2C2.SCL: P1.28
/(U1.A11)I2C1.SDA: P2.11
/(U1.A12)UART0.RX: P1.32, U1.7 (A6)
/(U1.A13)SPI0.CLK: P1.8
/(U1.A14)SPI0.CS: P1.6
/(U1.B1)PRU-0.3: P2.30, U2.5 (A4)
/(U1.B2)PRU-0.2: P2.32, U2.4 (A3)
/(U1.B3)PRU-0.5: P2.34, U2.7 (A6)
/(U1.B4)PRU-0.16: P1.20
/(U1.B6)AIN2~1.8V: P1.23
/(U1.B7)VREF+: P1.18
/(U1.B8)AIN1~1.8V: P1.21
/(U1.B9)VREF-: P1.17
/(U1.B10)I2C2.SDA: P1.26
/(U1.B11)I2C1.SCL: P2.9, U1.3 (A2)
/(U1.B12)UART0.TX: P1.30, U1.8 (A7)
/(U1.B13)SPI0.MISO: P1.10
/(U1.B14)SPI0.MOSI: P1.12
/(U1.C3)PRU-0.6: P2.28, U2.8 (A7)
/(U1.C4)PRU-0.7: P1.29, U2.9 (A8)
/(U1.C5)SPI1.CLK: P2.29
/(U1.C6)AIN3~1.8V: P1.25
/(U1.C7)AIN4~1.8V: P1.27
/(U1.C12)SPI1.MISO: P2.27
/(U1.C13)SPI1.MOSI: P2.25
/(U1.E1): P1.4, U1.6 (A5)
/(U1.F1): P1.35, U1.9 (A8)
/(U1.F2)AIN6~3.3V: P1.2, U1.5 (A4)
/(U1.F3)AIN5~3.3V: P2.35, U1.4 (A3)
/(U1.L14)USB1.ID: P1.13
/(U1.L15)USB1.D+: P1.11
/(U1.L16)USB1.D-: P1.9
/(U1.M14)USB1.DRVVBUS: P1.3
/(U1.M15)USB1.VBUS: P1.5
/(U1.N13)AIN7~1.8V: P2.36
/(U1.N14): P2.8
/(U1.P5)GPIO-0.23: P2.3
/(U1.P6): P2.24, U1.1 (A1)
/(U1.P7)PRU-0.15: P2.18
/(U1.P12)PWM1A: P2.1
/(U1.P15)UART4.RX: P2.5
/(U1.R5)GPIO-0.26: P1.34
/(U1.R6): P2.33
/(U1.R7): P2.20
/(U1.R11)RESET#: P2.26, R1.1, U1.10 (OE), U2.10 (OE)
/(U1.R13): P2.10
/(U1.R15): P2.4
/(U1.R16)UART4.TX: P2.7
/(U1.T5): P2.19
/(U1.T6)PRU-0.14: P2.22
/(U1.T7): P2.17
/(U1.T11)PWR.BTN: P2.12
/(U1.T15): P2.6
/(U1.T16): P2.2
/BAT.TEMP: P2.16
/PD0: JP4.1, U2.20 (B1)
/PD1: JP5.1, U2.18 (B2)
/PD2: JP6.1, U2.17 (B3)
/PD3: JP11.2, U2.16 (B4)
/PD4: JP10.2, U2.15 (B5)
/PD5: JP7.1, U2.14 (B6)
/PD6: JP8.1, U2.13 (B7)
/PD7: JP9.1, U2.12 (B8)
/PEX1: JP1.1, U1.14 (B6)
/PEX2: JP3.1, U1.15 (B5)
/PEX3: JP16.2, U1.12 (B8)
/PR/~W: JP2.1, U1.13 (B7)
/~PBSY: JP14.2, U1.17 (B3)
/~PCMD: JP13.2, U1.16 (B4)
/~PPARITY: JP12.2, U1.20 (B1)
/~PSTRB: JP15.2, U1.18 (B2)
GND: C1.2, C2.2, C3.2, C4.2, JP17.1, JP18.1, JP19.1, JP20.1, JP21.1, JP22.1, JP23.1, JP24.1, JP25.1, JP26.1, JP27.1, JP28.1, JP29.1, JP30.1, JP31.1, JP32.1, P1.15, P1.16, P1.22, P2.15, P2.21, P3.12, P3.14, P3.17, P3.19, P3.22, P3.24, P3.26, R1.2, U1.11 (GND), U2.11 (GND)
unnamed: JP1.2, JP17.2, P3.3, R2.2
unnamed: JP10.1, JP26.2, P3.20, R11.2
unnamed: JP11.1, JP27.2, P3.18, R12.2
unnamed: JP12.1, JP28.2, P3.10, R13.2
unnamed: JP13.1, JP29.2, P3.8, R14.2
unnamed: JP14.1, JP30.2, P3.6, R15.2
unnamed: JP15.1, JP31.2, P3.4, R16.2
unnamed: JP16.1, JP32.2, P3.2, R17.2
unnamed: JP2.2, JP18.2, P3.5, R3.2
unnamed: JP3.2, JP19.2, P3.7, R4.2
unnamed: JP4.2, JP20.2, P3.9, R5.2
unnamed: JP5.2, JP21.2, P3.11, R6.2
unnamed: JP6.2, JP22.2, P3.15, R7.2
unnamed: JP7.2, JP23.2, P3.21, R8.2
unnamed: JP8.2, JP24.2, P3.23, R9.2
unnamed: JP9.2, JP25.2, P3.25, R10.2
SYS_5V: C2.1, C4.1, P1.24, P2.13, R2.1, R3.1, R4.1, R5.1, R6.1, R7.1, R8.1, R9.1, R10.1, R11.1, R12.1, R13.1, R14.1, R15.1, R16.1, R17.1, U1.19 (V), U2.19 (V)
USB_DC: P1.7
VDD_3V3B: C1.1, C3.1, P1.14, P2.23, U1.2 (VCCA), U2.2 (VCCA)
VDD_5V: P1.1
VIN.BAT: P2.14

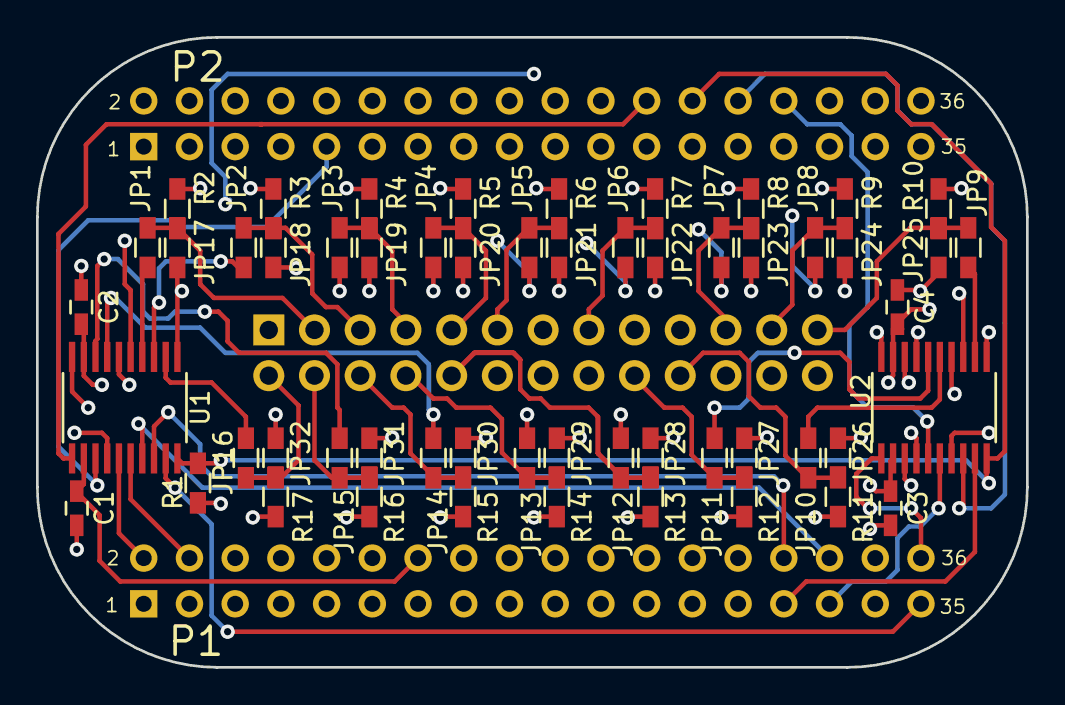
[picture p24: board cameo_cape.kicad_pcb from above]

Board: 4 copper layers, 55.0 x 35.0 mm, 58 parts (0 on the bottom side), 52 nets.

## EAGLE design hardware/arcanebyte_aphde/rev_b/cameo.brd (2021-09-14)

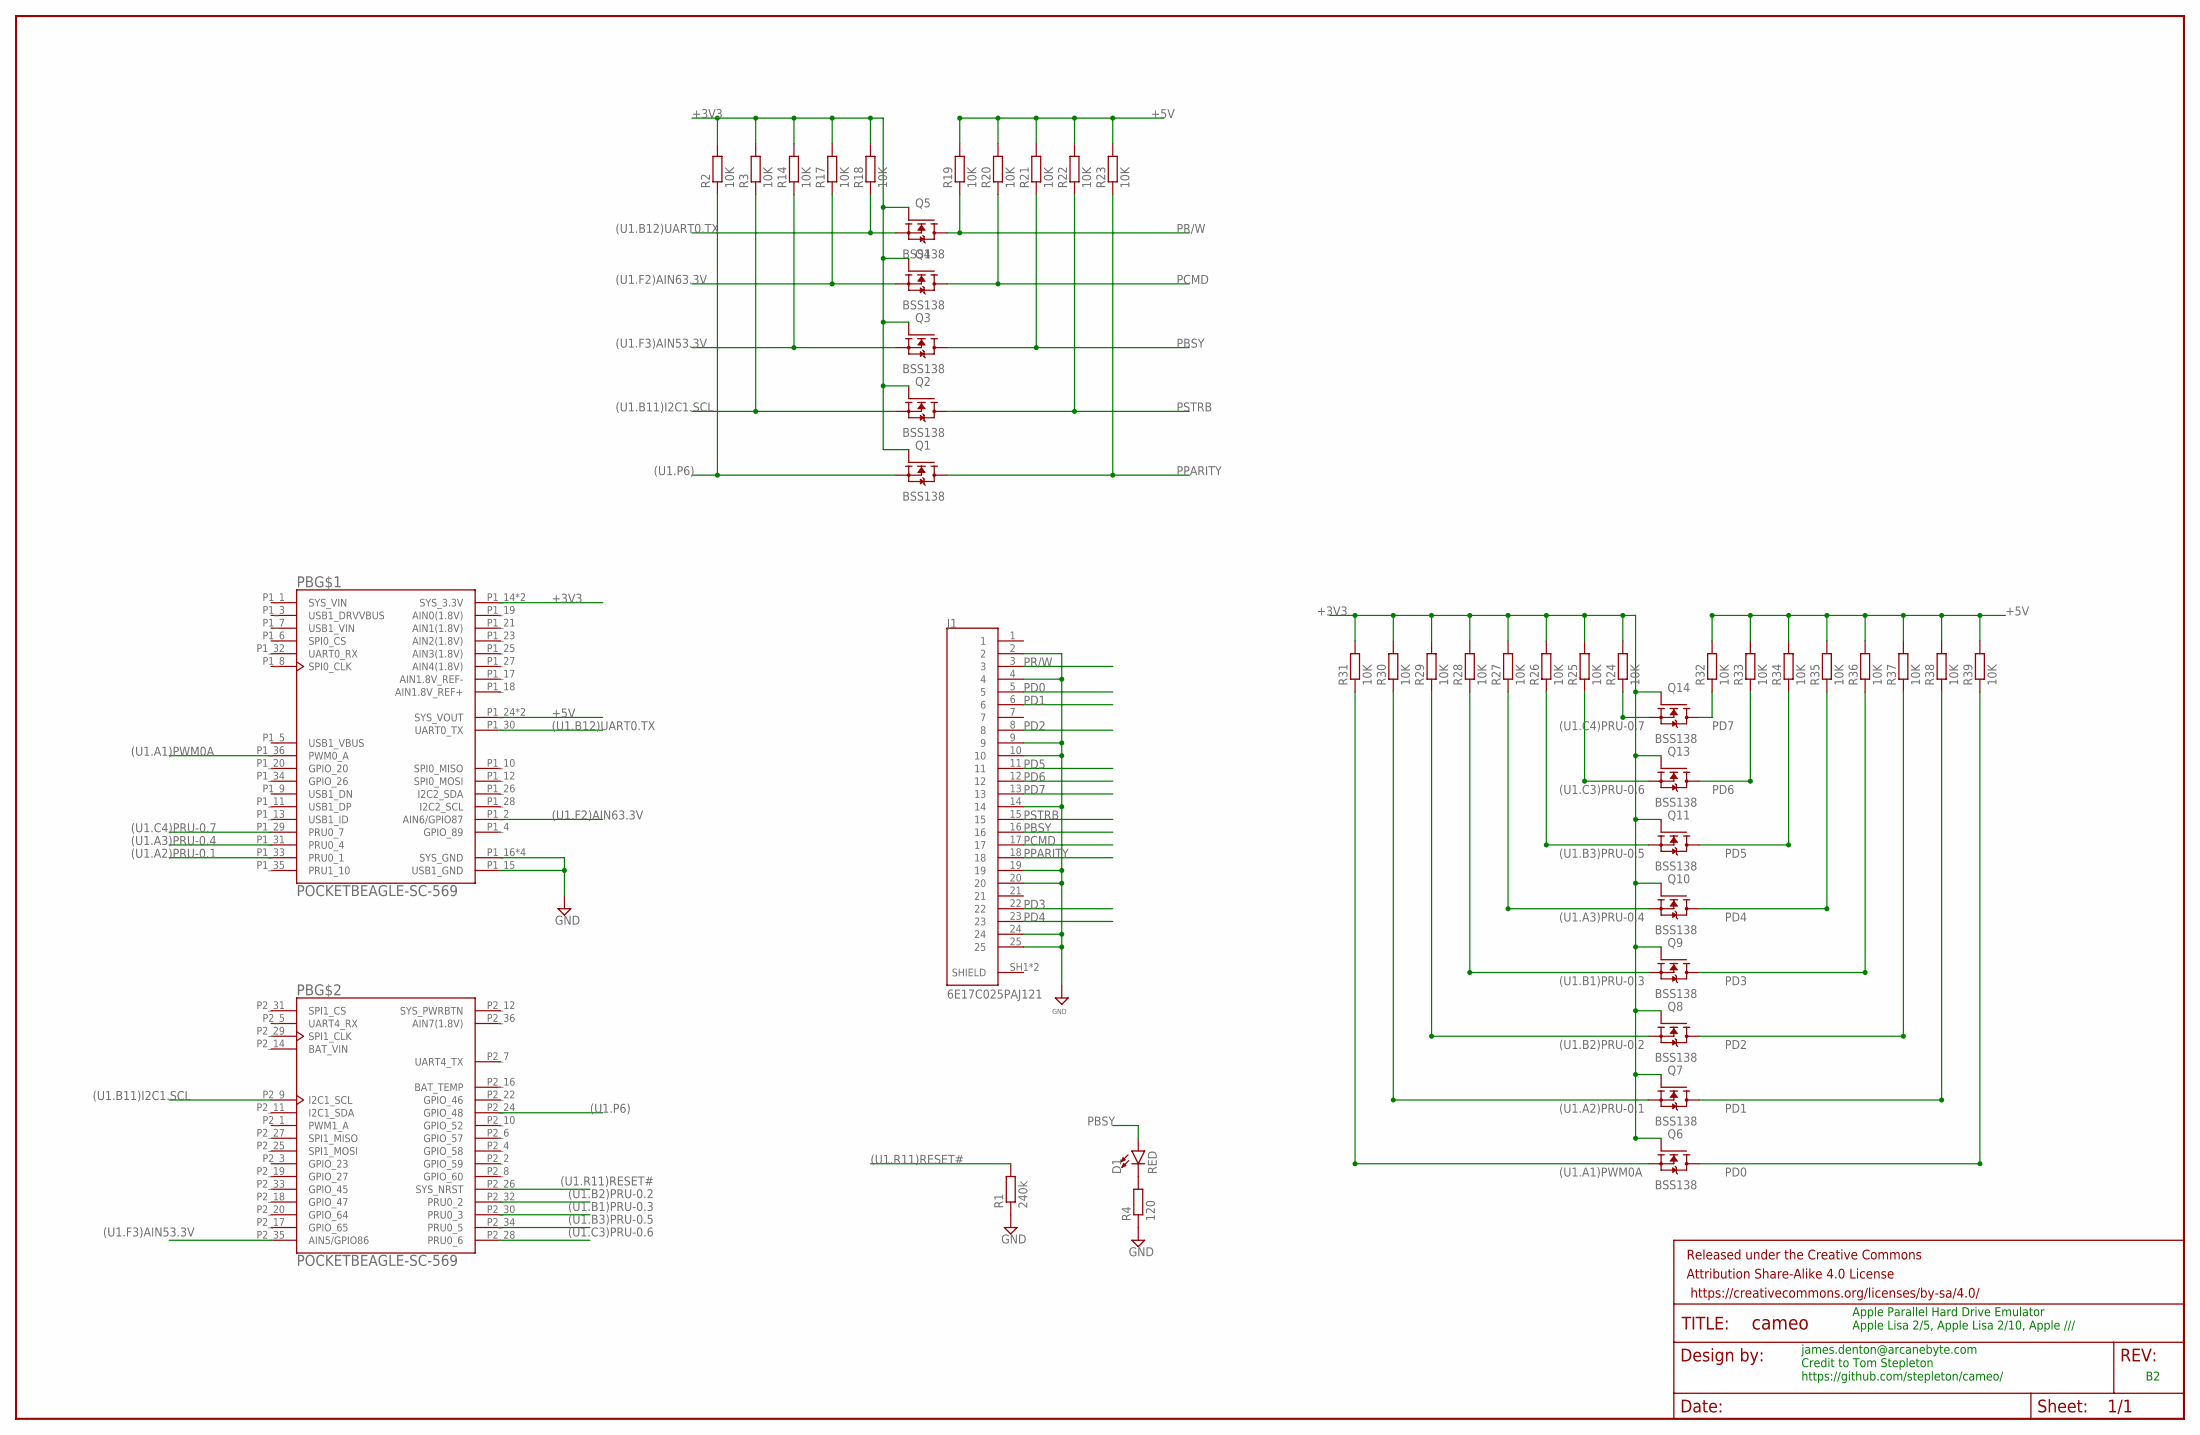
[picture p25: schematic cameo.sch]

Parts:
D1: RED; LED-0603
FRAME1: FRAME-LEDGER; CREATIVE_COMMONS
J1: 6E17C025PAJ121; CONN_6E17C025PAJ121
PB: POCKETBEAGLE-SC-569; BEAGLE_POCKETBEAGLE-SC-569
Q1, Q2, Q3, Q4, Q5, Q6, Q7, Q8, Q9, Q10, Q11, Q13, Q14: BSS138; SOT95P240X111-3N
R1: 240k; R0603
R2, R3, R14, R17, R18, R19, R20, R21, R22, R23, R24, R25, R26, R27, R28, R29, R30, R31, R32, R33, R34, R35, R36, R37, R38, R39: 10K; R0603
R4: 120; R0603

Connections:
(U1.A1)PWM0A: PB.P1_36 (PWM0_A), Q6.2 (S), R31.1
(U1.A2)PRU-0.1: PB.P1_33 (PRU0_1), Q7.2 (S), R30.1
(U1.A3)PRU-0.4: PB.P1_31 (PRU0_4), Q10.2 (S), R27.1
(U1.B1)PRU-0.3: PB.P2_30 (PRU0_3), Q9.2 (S), R28.1
(U1.B2)PRU-0.2: PB.P2_32 (PRU0_2), Q8.2 (S), R29.1
(U1.B3)PRU-0.5: PB.P2_34 (PRU0_5), Q11.2 (S), R26.1
(U1.B11)I2C1.SCL: PB.P2_9 (I2C1_SCL), Q2.2 (S), R3.1
(U1.B12)UART0.TX: PB.P1_30 (UART0_TX), Q5.2 (S), R18.1
(U1.C3)PRU-0.6: PB.P2_28 (PRU0_6), Q13.2 (S), R25.1
(U1.C4)PRU-0.7: PB.P1_29 (PRU0_7), Q14.2 (S), R24.1
(U1.F2)AIN63.3V: PB.P1_2 (AIN6/GPIO87), Q4.2 (S), R17.1
(U1.F3)AIN53.3V: PB.P2_35 (AIN5/GPIO86), Q3.2 (S), R14.1
(U1.P6): PB.P2_24 (GPIO_48), Q1.2 (S), R2.1
(U1.R11)RESET#: PB.P2_26 (SYS_NRST), R1.2
+3V3: PB.P1_14 (SYS_3.3V), PB.P2_23 (SYS_3.3V), Q1.1 (G), Q2.1 (G), Q3.1 (G), Q4.1 (G), Q5.1 (G), Q6.1 (G), Q7.1 (G), Q8.1 (G), Q9.1 (G), Q10.1 (G), Q11.1 (G), Q13.1 (G), Q14.1 (G), R2.2, R3.2, R14.2, R17.2, R18.2, R24.2, R25.2, R26.2, R27.2, R28.2, R29.2, R30.2, R31.2
+5V: PB.P1_24 (SYS_VOUT), PB.P2_13 (SYS_VOUT), R19.2, R20.2, R21.2, R22.2, R23.2, R32.2, R33.2, R34.2, R35.2, R36.2, R37.2, R38.2, R39.2
AIN0(1.8V): PB.P1_19 (AIN0(1.8V))
AIN1(1.8V): PB.P1_21 (AIN1(1.8V))
AIN1.8V_REF+: PB.P1_18 (AIN1.8V_REF+)
AIN1.8V_REF-: PB.P1_17 (AIN1.8V_REF-)
AIN2(1.8V): PB.P1_23 (AIN2(1.8V))
AIN3(1.8V): PB.P1_25 (AIN3(1.8V))
AIN4(1.8V): PB.P1_27 (AIN4(1.8V))
AIN7(1.8V): PB.P2_36 (AIN7(1.8V))
GND: J1.2, J1.4, J1.9, J1.10, J1.14, J1.19, J1.20, J1.24, J1.25, PB.P1_15 (USB1_GND), PB.P1_16 (SYS_GND), PB.P1_22 (SYS_GND), PB.P2_15 (SYS_GND), PB.P2_21 (SYS_GND), R1.1, R4.1
unnamed: D1.C, R4.2
PBSY: D1.A, J1.16, Q3.3 (D), R21.1
PCMD: J1.17, Q4.3 (D), R20.1
PD0: J1.5, Q6.3 (D), R39.1
PD1: J1.6, Q7.3 (D), R38.1
PD2: J1.8, Q8.3 (D), R37.1
PD3: J1.22, Q9.3 (D), R36.1
PD4: J1.23, Q10.3 (D), R35.1
PD5: J1.11, Q11.3 (D), R34.1
PD6: J1.12, Q13.3 (D), R33.1
PD7: J1.13, Q14.3 (D), R32.1
PPARITY: J1.18, Q1.3 (D), R23.1
PR/W: J1.3, Q5.3 (D), R19.1
PSTRB: J1.15, Q2.3 (D), R22.1
SYS_PWRBTN: PB.P2_12 (SYS_PWRBTN)

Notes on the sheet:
james.denton@arcanebyte.com Credit to Tom Stepleton https://github.com/stepleton/cameo/
Apple Parallel Hard Drive Emulator Apple Lisa 2/5, Apple Lisa 2/10, Apple ///

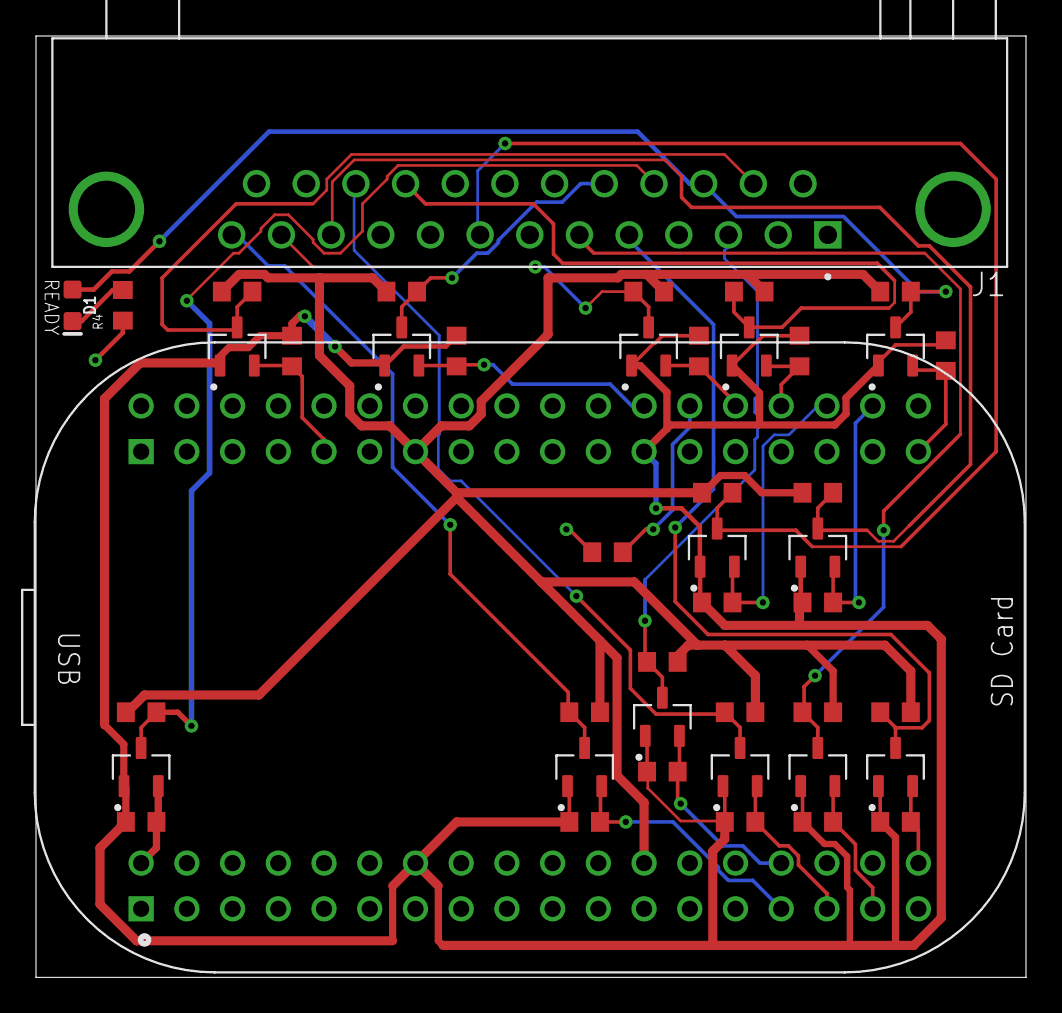
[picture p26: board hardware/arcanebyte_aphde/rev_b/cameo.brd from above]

Board: 2 copper layers, 55.0 x 52.3 mm, 45 parts (0 on the bottom side), 31 nets.

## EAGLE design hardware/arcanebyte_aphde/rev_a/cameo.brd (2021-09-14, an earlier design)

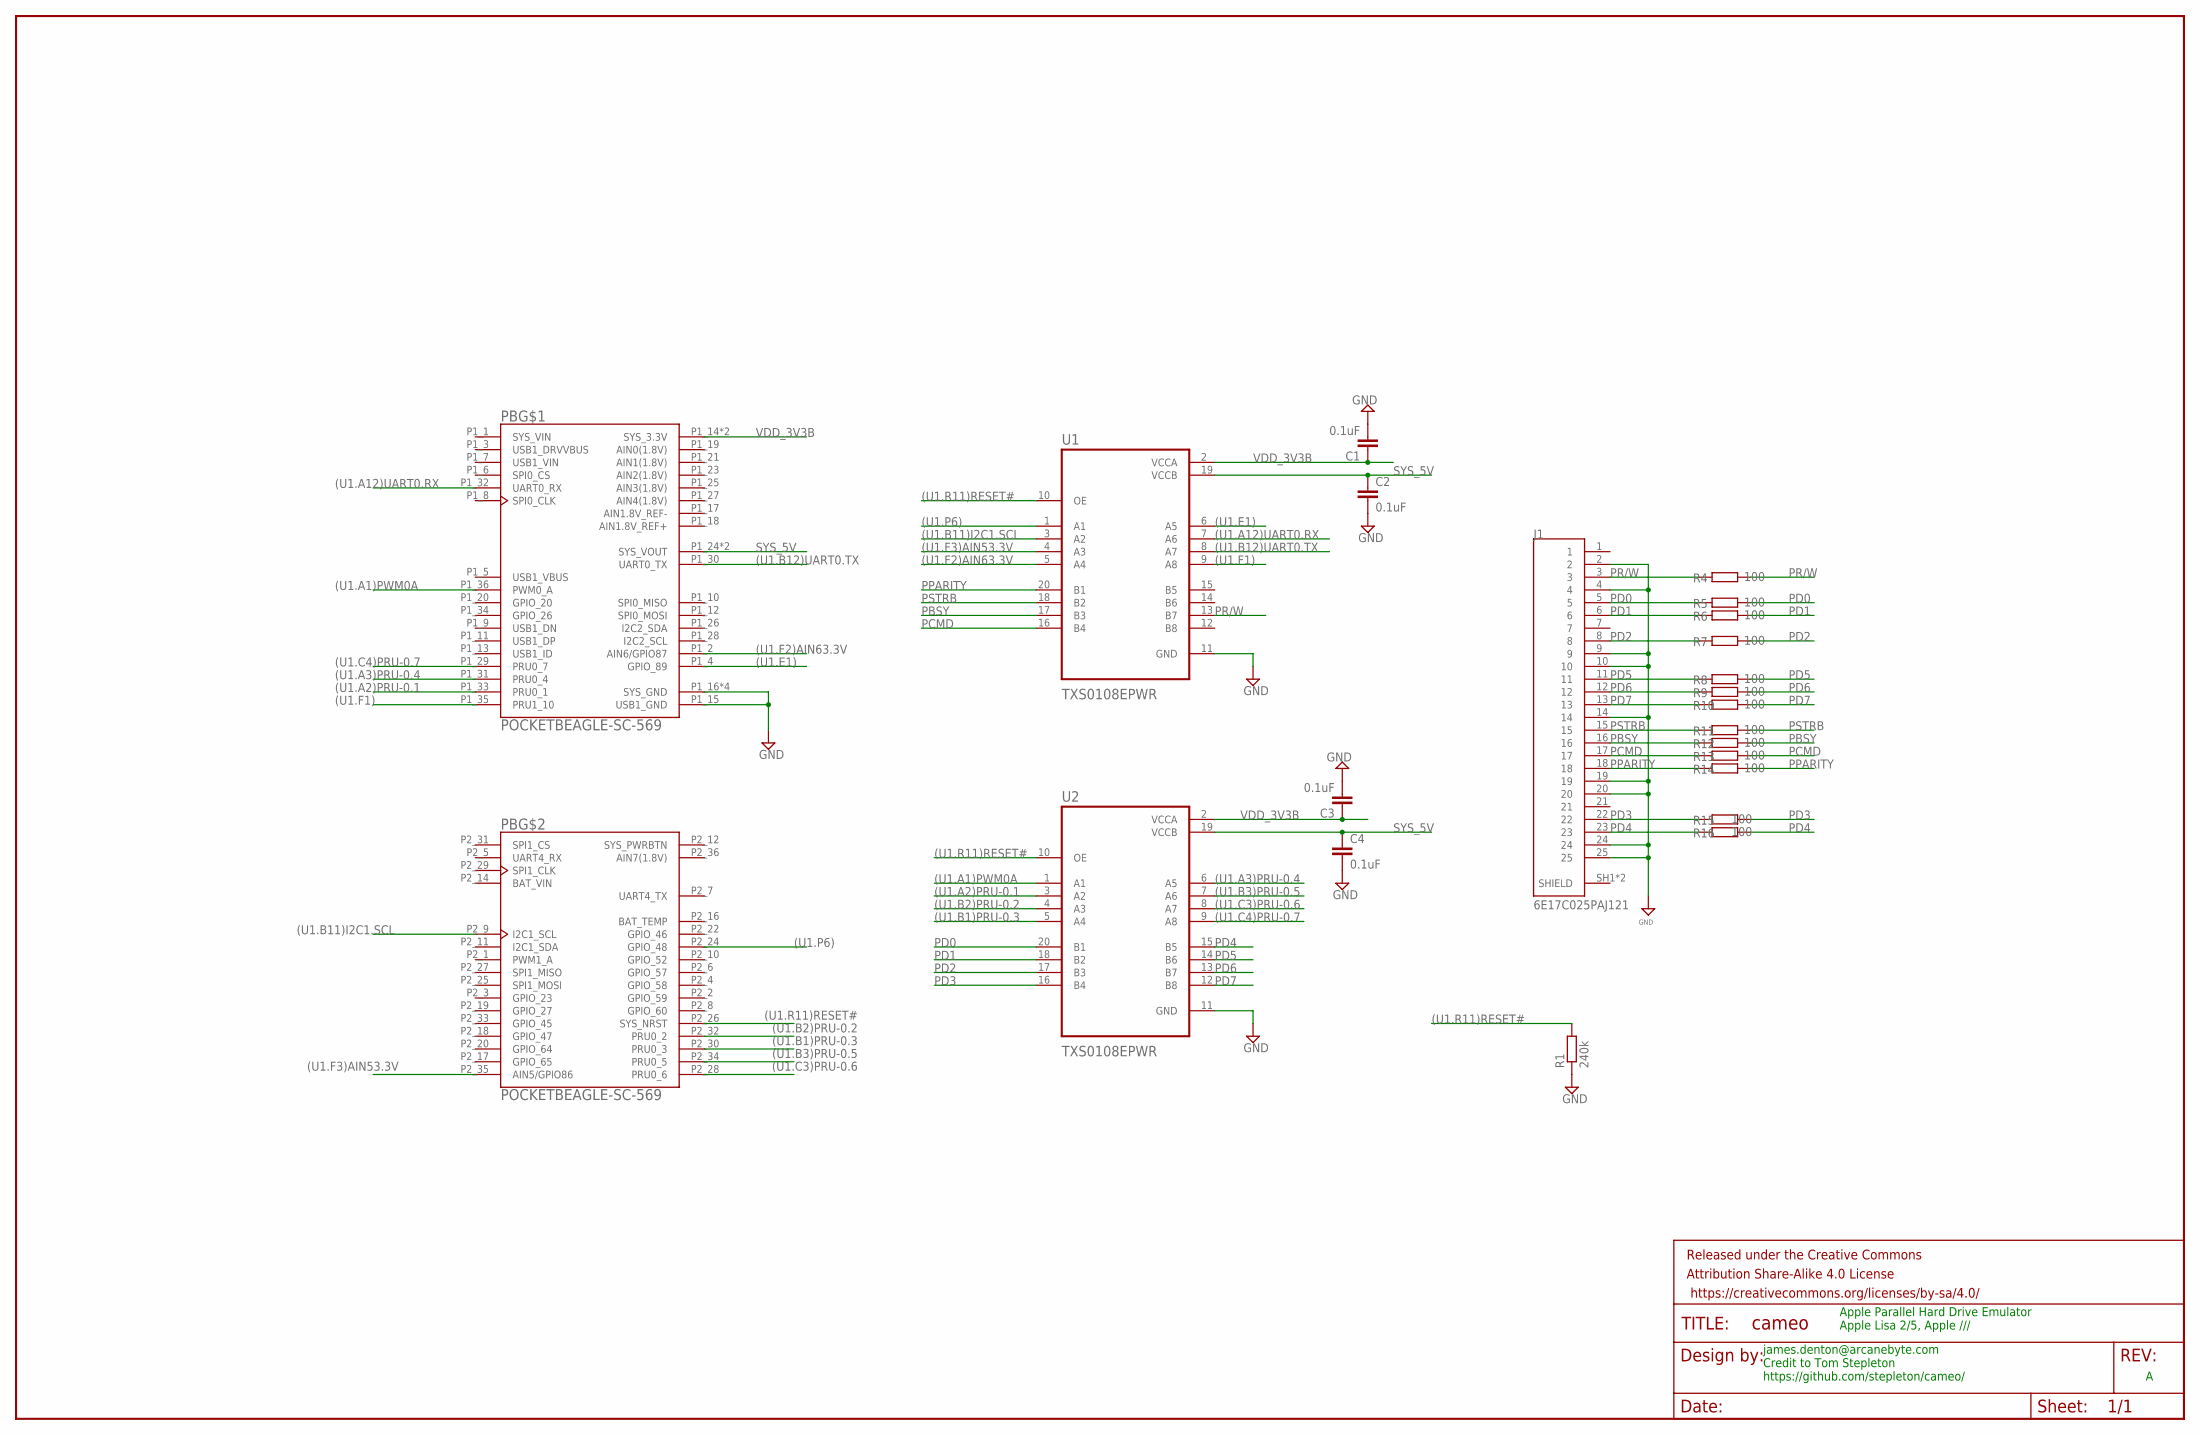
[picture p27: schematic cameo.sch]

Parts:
C1, C2, C3, C4: 0.1uF; C0603
FRAME1: FRAME-LEDGER; CREATIVE_COMMONS
J1: 6E17C025PAJ121; CONN_6E17C025PAJ121
PB: POCKETBEAGLE-SC-569; BEAGLE_POCKETBEAGLE-SC-569
R1: 240k; R0603
R4, R5, R6, R7, R8, R9, R10, R11, R12, R13, R14, R15, R16: 100; R0603
U1, U2: TXS0108EPWR; SOP65P640X120-20N

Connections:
(U1.A1)PWM0A: PB.P1_36 (PWM0_A), U2.1 (A1)
(U1.A2)PRU-0.1: PB.P1_33 (PRU0_1), U2.3 (A2)
(U1.A3)PRU-0.4: PB.P1_31 (PRU0_4), U2.6 (A5)
(U1.A12)UART0.RX: PB.P1_32 (UART0_RX), U1.7 (A6)
(U1.B1)PRU-0.3: PB.P2_30 (PRU0_3), U2.5 (A4)
(U1.B2)PRU-0.2: PB.P2_32 (PRU0_2), U2.4 (A3)
(U1.B3)PRU-0.5: PB.P2_34 (PRU0_5), U2.7 (A6)
(U1.B11)I2C1.SCL: PB.P2_9 (I2C1_SCL), U1.3 (A2)
(U1.B12)UART0.TX: PB.P1_30 (UART0_TX), U1.8 (A7)
(U1.C3)PRU-0.6: PB.P2_28 (PRU0_6), U2.8 (A7)
(U1.C4)PRU-0.7: PB.P1_29 (PRU0_7), U2.9 (A8)
(U1.E1): PB.P1_4 (GPIO_89), U1.6 (A5)
(U1.F1): PB.P1_35 (PRU1_10), U1.9 (A8)
(U1.F2)AIN63.3V: PB.P1_2 (AIN6/GPIO87), U1.5 (A4)
(U1.F3)AIN53.3V: PB.P2_35 (AIN5/GPIO86), U1.4 (A3)
(U1.P6): PB.P2_24 (GPIO_48), U1.1 (A1)
(U1.R11)RESET#: PB.P2_26 (SYS_NRST), R1.2, U1.10 (OE), U2.10 (OE)
AIN0(1.8V): PB.P1_19 (AIN0(1.8V))
AIN1(1.8V): PB.P1_21 (AIN1(1.8V))
AIN1.8V_REF+: PB.P1_18 (AIN1.8V_REF+)
AIN1.8V_REF-: PB.P1_17 (AIN1.8V_REF-)
AIN2(1.8V): PB.P1_23 (AIN2(1.8V))
AIN3(1.8V): PB.P1_25 (AIN3(1.8V))
AIN4(1.8V): PB.P1_27 (AIN4(1.8V))
AIN7(1.8V): PB.P2_36 (AIN7(1.8V))
GND: C1.2, C2.2, C3.2, C4.2, J1.2, J1.4, J1.9, J1.10, J1.14, J1.19, J1.20, J1.24, J1.25, PB.P1_15 (USB1_GND), PB.P1_16 (SYS_GND), PB.P1_22 (SYS_GND), PB.P2_15 (SYS_GND), PB.P2_21 (SYS_GND), R1.1, U1.11 (GND), U2.11 (GND)
PBSY: J1.16, R12.1, R12.2, U1.17 (B3)
PCMD: J1.17, R13.1, R13.2, U1.16 (B4)
PD0: J1.5, R5.1, R5.2, U2.20 (B1)
PD1: J1.6, R6.1, R6.2, U2.18 (B2)
PD2: J1.8, R7.1, R7.2, U2.17 (B3)
PD3: J1.22, R15.1, R15.2, U2.16 (B4)
PD4: J1.23, R16.1, R16.2, U2.15 (B5)
PD5: J1.11, R8.1, R8.2, U2.14 (B6)
PD6: J1.12, R9.1, R9.2, U2.13 (B7)
PD7: J1.13, R10.1, R10.2, U2.12 (B8)
PPARITY: J1.18, R14.1, R14.2, U1.20 (B1)
PR/W: J1.3, R4.1, R4.2, U1.13 (B7)
PSTRB: J1.15, R11.1, R11.2, U1.18 (B2)
SYS_5V: C2.1, C4.1, PB.P1_24 (SYS_VOUT), PB.P2_13 (SYS_VOUT), U1.19 (VCCB), U2.19 (VCCB)
SYS_PWRBTN: PB.P2_12 (SYS_PWRBTN)
VDD_3V3B: C1.1, C3.1, PB.P1_14 (SYS_3.3V), PB.P2_23 (SYS_3.3V), U1.2 (VCCA), U2.2 (VCCA)

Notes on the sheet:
james.denton@arcanebyte.com Credit to Tom Stepleton https://github.com/stepleton/cameo/
Apple Parallel Hard Drive Emulator Apple Lisa 2/5, Apple ///

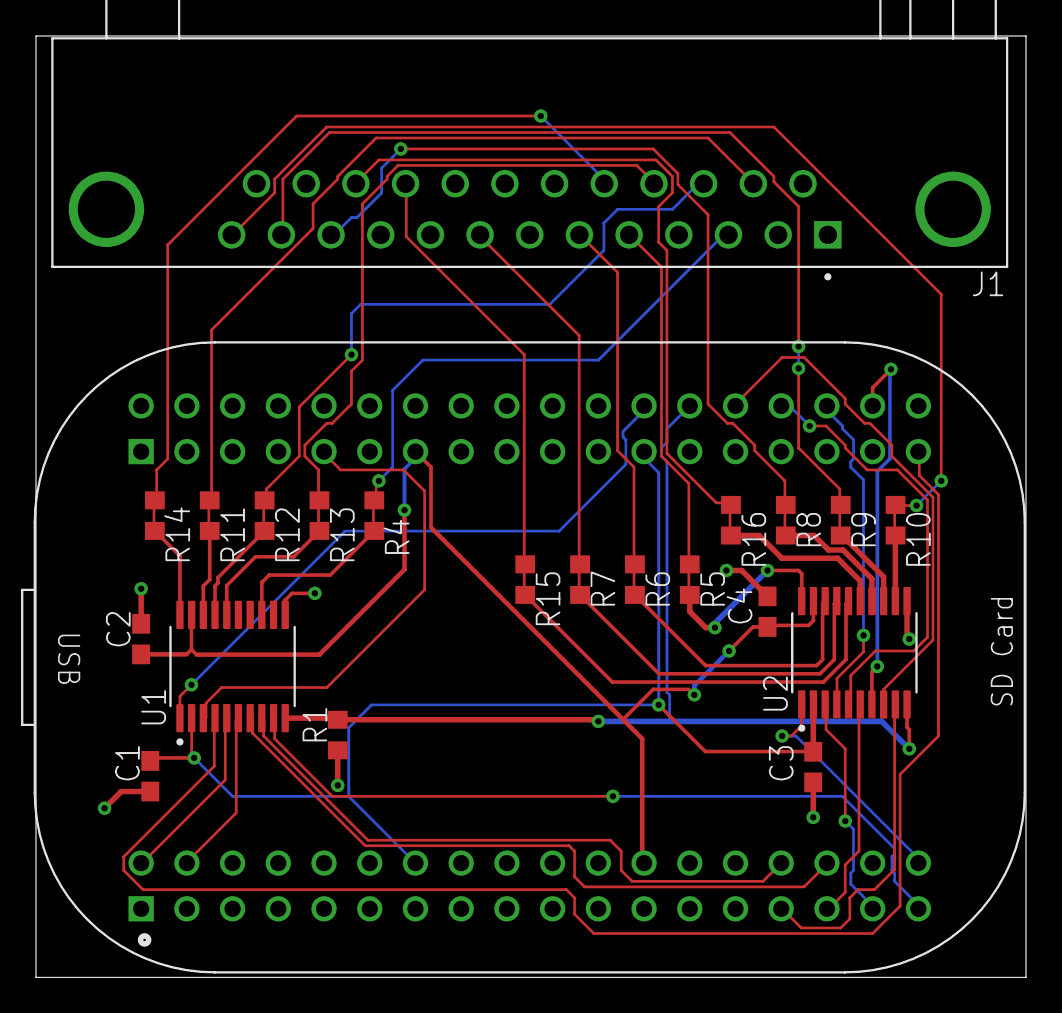
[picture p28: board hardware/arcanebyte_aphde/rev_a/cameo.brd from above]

Board: 2 copper layers, 55.0 x 52.3 mm, 23 parts (0 on the bottom side), 33 nets.

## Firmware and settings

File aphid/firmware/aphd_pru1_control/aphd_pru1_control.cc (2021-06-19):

// Aphid: Apple parallel port hard drive emulator for Cameo
//
// Forfeited into the public domain with NO WARRANTY. Read LICENSE for details.
//
// This file: firmware for PRU1; main program
//
// PRU1 is the "control processor" in charge of data exchange with the ARM and
// parallel port handshaking. PRU1 handles the \PCMD, \PBSY, and PR/\W signal
// lines directly, but issues commands to PRU0 (the "data pump") to move data
// in and out over the data lines whilst handling \PSTRB and \PPARITY.


#include <stdint.h>

#include <pru_cfg.h>
#include <pru_intc.h>

#include "aphd_pru_common.h"
#include "aphd_pru1_interrupt_and_buffer_handler.h"
#include "aphd_pru1_rpmsg.h"
#include "aphd_pru1_shared_memory.h"


/////////////////////
//// FRONTMATTER ////
/////////////////////


//// CONFIGURATION ////


// An "armless" PRU1 firmware does not request the ARM to copy data into or
// out of the buffers on reads or writes. The firmware is still capable of
// responding to buffer manipulation commands from the ARM, but it does not
// report to the ARM any commands received from the Apple.
#undef ARMLESS_MODE


// Set to true to enable various debug features that will slow execution.
// These features are:
// 1. Update (last_)control_debug_word in the shared memory region with various
//    bits of debug information (mainly: state machine state).
static const bool kDebug = true;


// This firmware has numerous loops where it waits on signal line changes,
// information from the ARM, and so forth. It shouldn't wait forever for these
// things to happen, so if this many iterations of the polling loop go past,
// it will eventually give up and wait for a new transaction. The particulars
// of each loop determine how long this many iterations will be in practice;
// suffice it to say, this value aims to be "a while" without being "too long".
//
// Certain loops multiply this value by 4; take care that the multiply would
// not overflow uint32.
static const uint32_t kTimeout = 0x10000000U;
// Some loops execute enough instructions between iterations that an equivalent
// timeout to the above is a few orders of magnitude fewer cycles.
static const uint32_t kTimeoutSB = kTimeout >> 4;


//// REGISTER SETUP ////


// Built-in symbols used for PRU GPIO pin access and interrupt handling.
extern "C" {
volatile register uint32_t __R30;
volatile register uint32_t __R31;
}  // extern "C"

// GPIO output enable control register. Usually PRU0 will set this itself; we
// use it only to throw data pins back into input mode in SendBytesWithParity*.
uint32_t volatile * const GPIO_OE =
    reinterpret_cast<uint32_t*>(0x481ae134U);

// GPIO data in register. Usually PRU0 will handle nearly all dealings with
// the data bus, but occasionally we need to spy on it ourselves.
uint32_t volatile * const GPIO_DATAIN =
    reinterpret_cast<uint32_t*>(0x481ae138U);


//////////////
//// CODE ////
//////////////


//// LOW-LEVEL I/O ////


// Predeclarations.
uint8_t _NormalCleanup(const bool& reassert_interrupt_from_arm);
uint8_t _AbnormalCleanup(const bool& reassert_interrupt_from_arm);


// Resets PRU0 to the idle state (where it awaits a new command).
//
// Per the recommended reset procedure described in aphd_pru0_datapump.asm,
// repeatedly issues an invalid command to PRU0 until it receives an error
// response that means "invalid command" (0x01).
//
// Will loop forever until it receives this response.
inline void ResetDataPump() {
  // Repeat forever until we get a 0x01 response from the PRU.
  for (;;) {
    // 1. Await PRU1 to PRU0 interrupt clear. Normally we wouldn't check this
    // ourselves, but in the reset routine we don't know what state PRU0 is in,
    // and we don't want to issue an interrupt until we know that PRU0 is ready
    // for it. As long as the firmware is running, it should clear this
    // interrupt in fairly short order.
    while ((CT_INTC.SECR0 & (1 << ePRU1to0)) != 0);

    // 2. Deliberately prepare an invalid command for the PRU. (Size and address
    // fields don't matter for invalid commands.)
    SHMEM.data_pump_command.return_code = 0xff;  // PRU0 should change this
    SHMEM.data_pump_command.command = dINVALID;  // An invalid command code

    // 3. Try to invoke the data pump.
    CT_INTC.SICR = ePRU0to1;  // Clear PRU0 to PRU1 interrupt
    __R31 = sPRU1to0;         // Wake up PRU0 with an interrupt

    // 4. Wait for the data pump to get back to us.
    for (;;) {
      // If we got an interrupt...
      if ((__R31 & (1U << iAnyToPRU1)) != 0) {
        // ...clear it, and if it came from the ARM, handle it before you do
        // that as well. But if it came from PRU0...
        if (kImPru0 == handle_interrupt()) {
          // ...then return if the return code is 0x01 ("invalid command")...
          if (SHMEM.data_pump_command.return_code == 0x01) return;
          // ...otherwise break and send another invalid command.
          break;
        }
      }
    }
  }
}


// Commands PRU0 to send bytes with parity information over the data lines.
//
// StartSendBytesWithParity issues a command to PRU0 (the "data pump") to send
// data accompanied by parity information out over the data lines, clocked
// externally by the \PSTRB line. The function returns immediately after issuing
// the command.
//
// The data to send must be supplied as <data byte><parity byte> pairs, with
// the sixth bit of <parity byte> supplying odd parity for <data byte>. The
// other bits are ignored, so it is safe to use values like 0x00 and 0xFF,
// provided the sixth bit is set appropriately.
//
// The WaitSendBytesWithParity function blocks until the data pump either
// completes the transfer or times out. **Any call to StartSendBytesWithParity
// MUST be followed very shortly by a call to WaitSendBytesWithParity**, which
// must be running to avoid data line contention if the Apple ever unexpectedly
// drops the PR/\W line.
//
// Args:
//   addr: Starting address for <data byte><parity byte> pairs to write to the
//       data lines. This address should be in PRU0's address space; take care
//       that none of the data to write lives in the first eight bytes of the
//       shared memory space.
//   size: Number of <data byte><parity byte> pairs to write to the data lines.
inline void StartSendBytesWithParity(const volatile ByteParityPair* const addr,
                                     uint16_t size) {
  // 0. We haven't told the data pump to do anything yet, so clear out any
  // lingering interrupts without worrying about where they came from.
  while ((__R31 & (1U << iAnyToPRU1)) != 0) handle_interrupt();

  // 1. Construct the data pump command in shared memory.
  SHMEM.data_pump_command.return_code = 0xff;  // PRU0 should change this
  SHMEM.data_pump_command.command = dWRITE;    // PRU0 should send data out
  SHMEM.data_pump_command.size = size;         // In particular, this many pairs
  SHMEM.data_pump_command.address = reinterpret_cast<uint32_t>(addr);  // Hence

  // 2. Invoke the data pump. PRU0 will select output mode for the data lines
  // and start sending data.
  CT_INTC.SICR = ePRU0to1;  // Clear PRU0 to PRU1 interrupt
  __R31 = sPRU1to0;         // Wake up PRU0 with an interrupt
}


// Loop until PRU0 finishes sending bytes with parity info over the data lines.
//
// This function should only (and must) be called after a call to
// StartSendBytesWithParity: it waits for termination of the data transfer
// operation that that function initiates.
//
// While waiting for PRU0 to complete the transfer (or time out), this function
// monitors the PR/\W line. If it falls, it immediately reverts the data pins to
// input mode, since the Apple has claimed the bus; it then sends an interrupt
// interrupt to PRU0 to cancel the write. Note that PRU0 might still indicate
// that the command was successful: if the last byte went out on the bus, we
// assume the Apple has read it (sometimes it doesn't clock the last byte and
// instead just toggles PR/\W in preparation to send a $55 acknowledgement).
//
// In order to perform PR/\W monitoring reliably, this function should be called
// as soon as possible after StartSendBytesWithParity returns.
//
// Args:
//   timeout: If nonzero, polls the control lines this many times before giving
//       up, interrupting the transfer, and returning.
//
// Returns:
//   0: Data transfer was successful.
//   4: Transfer interrupted waiting for \PSTRB to go low.
//   5: Transfer interrupted waiting for \PSTRB to go high.
uint8_t WaitSendBytesWithParity(uint32_t timeout = 0) {
  const register uint32_t ones = 0xffffffffU;  // In a register for fast copy
  register bool reassert_interrupt_from_arm = false;  // Also for speed

  // 3a. Now wait for the data pump to finish. If PR/\W goes low, select input
  // mode for the data lines to avoid bus conflicts; normally, PRU0 will do
  // this when it finishes. Meanwhile, \PCMD may *start* low---rising edges are
  // OK with us. There is hypothetically a *RACE* here: \PCMD could fall just
  // prior to this point, though this would probably be an abnormal and unlucky
  // situation if WaitSendBytesWithParity is called under ordinary conditions.
  while ((__R31 & (1U << ppCMD)) == 0) {
    // Decrement timeout counter where applicable.
    if (timeout != 0) {
      if (--timeout == 0) {
        *GPIO_OE = ones;  // Data pins to input mode NOW!
        return _AbnormalCleanup(reassert_interrupt_from_arm);
      }
    }
    // If the Apple lowers PR/\W, set data pins to input mode immediately! Then
    // send an interrupt to PRU0 to cancel the write.
    if ((__R31 & (1U << ppRW)) == 0) {
      *GPIO_OE = ones;  // Data pins to input mode NOW!
      return _AbnormalCleanup(reassert_interrupt_from_arm);
    }
    // If there is an interrupt, then if it's from the ARM, we'll clear it for
    // now and deal with it later (allowing us to keep monitoring the PR/\W
    // lines closely. Otherwise, we assume that it's from PRU0 and we jump ahead
    // to return. We should try not to get many interrupts from the ARM during
    // this busy time, regardless---this could be a flaky solution.
    if ((__R31 & (1U << iAnyToPRU1)) != 0) {
      if ((CT_INTC.SECR0 & (1 << eARMtoPRU1)) != 0) {
        reassert_interrupt_from_arm = true;
        CT_INTC.SICR = eARMtoPRU1;
      } else {
        // If here, data pins are already in input mode.
        return _NormalCleanup(reassert_interrupt_from_arm);
      }
    }
  }

  // 3b. If \PCMD was originally high or if there was a rising edge, keep on
  // waiting for the data pump to finish, as long as \PCMD stays high. We use
  // the same logic from the previous loop.
  while ((__R31 & (1U << ppCMD)) != 0) {
    if (timeout != 0) {
      if (--timeout == 0) {
        *GPIO_OE = ones;
        return _AbnormalCleanup(reassert_interrupt_from_arm);
      }
    }
    if ((__R31 & (1U << ppRW)) == 0) {
      *GPIO_OE = ones;
      return _AbnormalCleanup(reassert_interrupt_from_arm);
    }
    if ((__R31 & (1U << iAnyToPRU1)) != 0) {
      if ((CT_INTC.SECR0 & (1 << eARMtoPRU1)) != 0) {
        reassert_interrupt_from_arm = true;
        CT_INTC.SICR = eARMtoPRU1;
      } else {
        return _NormalCleanup(reassert_interrupt_from_arm);
      }
    }
  }


  // 4. But if we're here, \PCMD has fallen. We must cancel the data pump's
  // current operation and wait for it to send us an interrupt to indicate that
  // it's done. We
  *GPIO_OE = ones;  // Set data pins to input mode as a precaution.
  return _AbnormalCleanup(reassert_interrupt_from_arm);
}


// Commands PRU0 to send bytes with parity information over the data lines.
//
// Calls StartSendBytesWithParity and WaitSendBytesWithParity. See documentation
// at those functions for details.
//
// Args:
//   addr: Starting address for <data byte><parity byte> pairs to write to the
//       data lines. This address should be in PRU0's address space; take care
//       that none of the data to write lives in the first eight bytes of the
//       shared memory space.
//   size: Number of <data byte><parity byte> pairs to write to the data lines.
//   timeout: If nonzero, polls the control lines this many times before giving
//       up, interrupting the transfer, and returning.
//
// Returns:
//   0: Data transfer was successful.
//   4: Transfer interrupted waiting for \PSTRB to go low.
//   5: Transfer interrupted waiting for \PSTRB to go high.
inline uint8_t SendBytesWithParity(const volatile ByteParityPair* const addr,
                                   uint16_t size, uint32_t timeout = 0) {
  StartSendBytesWithParity(addr, size);
  return WaitSendBytesWithParity(timeout);
}


// Commands PRU1 to receive bytes over the data lines.
//
// ReceiveBytes issues a command to PRU0 (the "data pump") to read data in from
// the data lines, clocked externally by the \PSTRB line. The function normally
// waits for PRU0 to complete the transfer, but it will terminate prematurely
// with a nonzero return code on a \PCMD falling edge.
//
// (As an example case where this precaution might be relevant: imagine that
// the Apple crashes halfway through clocking in bytes to write to the disk.
// \PCMD may remain high throughout the Apple's reboot process, but the Apple
// is unlikely to resume the transaction where it left off. When it is finally
// ready to talk to the disk again, it will lower \PCMD to initiate a new
// command, and that's the rising edge that causes us abort the data pump's read
// operation.)
//
// Args:
//   addr: Starting address for the memory region receiving bytes from the data
//       lines. This address should be in PRU0's address space.
//   size: Number of bytes to read from the data lines; should be above 0.
//   timeout: If nonzero, polls the control lines this many times before giving
//       up, interrupting the transfer, and returning.
//
// Returns:
//   0: Data transfer was successful.
//   2: Transfer interrupted waiting for \PSTRB to go low.
//   3: Transfer interrupted waiting for \PSTRB to go high.
uint8_t ReceiveBytes(volatile uint8_t* const addr, uint16_t size,
                     uint32_t timeout = 0) {
  // A useful alias.
  volatile uint8_t* const return_code = &SHMEM.data_pump_command.return_code;

  // 0. We haven't told the data pump to do anything yet, so clear out any
  // lingering interrupts without worrying about where they came from.
  while ((__R31 & (1U << iAnyToPRU1)) != 0) handle_interrupt();

  // 1. Construct the data pump command.
  SHMEM.data_pump_command.return_code = 0xff;  // PRU0 should change this
  SHMEM.data_pump_command.command = dREAD;     // PRU0 should read data in
  SHMEM.data_pump_command.size = size;         // In particular, this many bytes
  SHMEM.data_pump_command.address = reinterpret_cast<uint32_t>(addr);  // Thence

  // 2. Invoke the data pump. PRU0 will start reading data.
  CT_INTC.SICR = ePRU0to1;  // Clear PRU0 to PRU1 interrupt
  __R31 = sPRU1to0;         // Wake up PRU0 with an interrupt

  // 3a. Now wait for the data pump to finish. \PCMD may *start* low---rising
  // edges are OK with us. There is hypothetically a *RACE* here: \PCMD could
  // fall just prior to this point, though this would probably be an abnormal
  // and unlucky situation if ReceiveBytes is called under ordinary conditions.
  while ((__R31 & (1U << ppCMD)) == 0) {
    // Decrement timeout counter where applicable.
    if (timeout != 0) {
      if (--timeout == 0) return _AbnormalCleanup(false);
    }
    // If we got an interrupt...
    if ((__R31 & (1U << iAnyToPRU1)) != 0) {
      // ...and if it came from PRU0, then break. If it came from the ARM, the
      // interrupt handler will just do whatever data transfer thing the ARM
      // needed to do. Either way, the PRU0 to PRU1 interrupt will be cleared
      // upon breaking out of the loop.
      if (kImPru0 == handle_interrupt()) return *return_code;
    }
  }

  // 3b. If \PCMD was originally high or if there was a rising edge, keep on
  // waiting for the data pump to finish, as long as \PCMD stays high. We use
  // the same logic from the previous loop.
  while ((__R31 & (1U << ppCMD)) != 0) {
    if (timeout != 0) {
      if (--timeout == 0) return _AbnormalCleanup(false);
    }
    if ((__R31 & (1U << iAnyToPRU1)) != 0) {
      if (kImPru0 == handle_interrupt()) return *return_code;
    }
  }

  // 4. But if we're here, \PCMD has fallen. We must cancel the data pump's
  // current operation and wait for it to send us an interrupt to indicate that
  // it's done.
  return _AbnormalCleanup(false);
}


// Helper for ReceiveBytes, WaitSendBytesWithParity: handle "normal" cleanup.
//
// Call only after PRU0 has issued an interrupt indicating that the transfer
// is complete!
//
// Args:
//   reassert_interrupt_from_arm: If set, the caller has deferred an interrupt
//       from the ARM, and this routine should reassert this interrupt and
//       then handle it. The caller should endeavour not to allow more than one
//       interrupt from the ARM to be deferred; only one interrupt can be
//       handled in this way.
//
// Returns:
//   See return details at ReceiveBytes or WaitSendBytesWithParity, depending on
//   who the caller was.
inline uint8_t _NormalCleanup(const bool& reassert_interrupt_from_arm) {
  if(reassert_interrupt_from_arm) {
    __R31 = sARMtoPRU1;
    handle_interrupt();
  }
  return SHMEM.data_pump_command.return_code;
}


// Helper for ReceiveBytes, WaitSendBytesWithParity: handle "abnormal" cleanup.
//
// Issues an interrupt to PRU0 to terminate a data transfer operation in
// progress, then awaits an interrupt from PRU0 signalling that termination has
// occurred and that PRU0 has returned to the idle state.
//
// Args:
//   reassert_interrupt_from_arm: If set, the caller has deferred an interrupt
//       from the ARM, and this routine should reassert this interrupt and
//       then handle it. The caller should endeavour not to allow more than one
//       interrupt from the ARM to be deferred; only one interrupt can be
//       handled in this way.
//
// Returns:
//   See return details at ReceiveBytes or WaitSendBytesWithParity, depending on
//   who the caller was.
inline uint8_t _AbnormalCleanup(const bool& reassert_interrupt_from_arm) {
  __R31 = sPRU1to0;  // Trigger an interrupt of PRU0.
  for (;;) {
    if ((__R31 & (1U << iAnyToPRU1)) != 0) {  // Await the PRU0 response...
      if (kImPru0 == handle_interrupt()) { //...and here it is.
        return _NormalCleanup(reassert_interrupt_from_arm);
      }
    }
  }
}


//// OTHER HELPERS ////


// Send the six command bytes from the Apple to the ARM via RPMsg.
//
// The transfer is attempted up to five times. Returns true on success.
inline bool send_apple_command_to_arm() {
  for (int i = 0; i < 5; ++i) {
    void* buffer = const_cast<uint8_t*>(SHMEM.apple_command);
    if (aphd_pru1_rpmsg_send(buffer, sizeof(SHMEM.apple_command)) == 0) {
      return true;
    }
  }
  return false;
}


//// STATE MACHINE ////


// Predeclarations.
void state_machine_read();
void state_machine_write(const uint8_t command);
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
void main(void) {
  // Setup.
  CT_CFG.SYSCFG_bit.STANDBY_INIT = 0;  // Enable OCP master port
  aphd_pru1_rpmsg_init();  // Initialise RPMsg system
  ResetDataPump();  // Force data pump into a known state

  // Main loop.
  for (;;) state_machine_idle();

#pragma diag_suppress=112
  // PRU core halts, or it would if we could reach this line.
  __halt();
}

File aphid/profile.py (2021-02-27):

#!/usr/bin/python3
"""Apple parallel port storage emulator for Cameo

Forfeited into the public domain with NO WARRANTY. Read LICENSE for details.

When run atop the entire Cameo cape/Aphid PRU firmware stack, emulates a
ProFile hard drive. Backing storage is a single file (a "disk image file")
mmap'd into this program's process space. For accurate simulation of an
ordinary 5 MB ProFile, the disk image file should be 5,175,296 bytes in size,
for a ProFile-10, 10,350,592 bytes. Any other drive image announces itself to
the Apple as a 5 MB ProFile with a strange number of available blocks, a
convention intended to replicate the behaviour of X/ProFile.

Run with the --help flag for usage information.

Includes a plugin system that allows some blocks to be "magical". See the
file header comment in `profile_plugins.py` for details.

Most installations of the emulator will run in "headless" mode (i.e. without
any console for displaying log messages), so this program displays some basic
status information on the user LEDs. Light patterns and their meanings include:

* All four LEDs on "solid": the emulator is ready to serve requests from
  the Apple. (When it does, the LEDs will blink off momentarily, much like
  the "READY" LED on a real drive.) While in this mode, the emulator may lose
  data if it is shut down unexpectedly.

* Rapid "cycling" pattern: the emulator is either initialising or awaiting
  system shutdown; either way, to the fullest extent that this program can
  guarantee it, all data should be written to the storage device.

* The two centre LEDs blink slowly in unison: the emulator has encountered an
  unrecoverable error and is busy doing nothing. All attempts have been made to
  preserve the disk image data. Try restarting the PocketBeagle. 

Any other light pattern that persists at length is either an indication that
the emulator is not running or that some other, unforeseen error has occurred.
"""

import argparse
import contextlib
import logging
import mmap
import os
import select
import signal
import struct
import sys
import threading
import time

from typing import BinaryIO, Dict, Generator, Iterator, Optional, Tuple, NamedTuple

import profile_plugins


###################
#### Constants ####
###################


IMAGE_SIZE_P5  = 5175296   # 5 MB ProFile hard drive image size in bytes.
IMAGE_SIZE_P10 = 10350592  # 10 MB ProFile hard drive image size in bytes.

SECTOR_SIZE = 532  # Sector size in bytes. Cf. "block size" in spare tables.

# This "secret" Cameo/Aphid device ID and protocol version is appended to the
# end of the sector $FFFFFF spare table data structure, allowing software to
# identify when a Cameo/Aphid is present (and how to talk to it). For major
# revisions to this protocol (which includes the format of writes to $FFFFFD
# and to various standard (whatever that means) "magic blocks" plugins),
# increment the 4-digit number at the end.
CAMEO_APHID_ID = b'Cameo/Aphid 0001'

# For the beginning of command messages that tell the Aphid PRU1 firmware to
# execute various operations, we use statistically-unusual sequences of bytes.
APHD_COMMAND_GET_PART_1 = b'\x8c\xa9\x37\xf1' + struct.pack('<HH', 0, 266)
APHD_COMMAND_GET_PART_2 = b'\x8c\xa9\x37\xf1' + struct.pack('<HH', 266, 266)
APHD_COMMAND_PUT_PART_1 = b'\xdb\x95\x4b\xc7' + struct.pack('<HH', 0, 354)
APHD_COMMAND_PUT_PART_2 = b'\xdb\x95\x4b\xc7' + struct.pack('<HH', 354, 354)
APHD_COMMAND_PUT_PART_3 = b'\xdb\x95\x4b\xc7' + struct.pack('<HH', 708, 356)
APHD_COMMAND_GOAHEAD = b'\xa6\x93\x73\xea' + struct.pack('<HH', 0, 0)

# Here are the various ProFile operations that we pretend to do.
PROFILE_READ = 0x00
PROFILE_WRITE = 0x01
PROFILE_WRITE_VERIFY = 0x02
PROFILE_WRITE_FORCE_SPARE = 0x03
ALL_PROFILE_WRITE_COMMANDS = (
    PROFILE_WRITE, PROFILE_WRITE_VERIFY, PROFILE_WRITE_FORCE_SPARE)

# Paths to the filesystem objects that allow us to configure the pinmux.
OCP_PREFIX = '/sys/devices/platform/ocp/'
GPIO_PREFIX = '/sys/class/gpio/gpio'

# Paths to the filesystem objects that allow us to choose PRU firmware.
PRU0_STATE_PATH = '/sys/class/remoteproc/remoteproc1/state'
PRU1_STATE_PATH = '/sys/class/remoteproc/remoteproc2/state'
PRU0_FW_CHOOSER_PATH = '/sys/class/remoteproc/remoteproc1/firmware'
PRU1_FW_CHOOSER_PATH = '/sys/class/remoteproc/remoteproc2/firmware'
PRU0_FW_NAME = 'aphd_pru0_datapump.fw'
PRU1_FW_NAME = 'aphd_pru1_control.fw'

# Paths to the filesystem objects that allow us to control LEDs.
LED_PREFIX = '/sys/class/leds/beaglebone:green:usr'

# The device we use to communicate with PRU1 over RPMsg
RPMSG_DEVICE = '/dev/rpmsg_pru31'

# Precomputed even parity lookup table.
PARITY = tuple(0x00 if bin(c).count('1') % 2 else 0xff for c in range(256))


##############################
#### Command-line parsing ####
##############################


def _define_flags() -> argparse.ArgumentParser:
  """Defines an `ArgumentParser` for command-line flags used by this program."""

  flags = argparse.ArgumentParser(description='Cameo/Aphid ProFile emulator.')
  flags.add_argument(
      '-d', '--device', type=str, default=RPMSG_DEVICE, help=(
          'Device file for the RPMsg connection to PRU 1. By default, this '
          'is {}.'.format(RPMSG_DEVICE)))
  flags.add_argument(
      '-v', '--verbose', action='store_true', help=(
          'Enable verbose logging.'))
  flags.add_argument(
      '-c', '--create', action='store_true', help=(
          'Create the empty hard drive image file image_file if it does not '
          'already exist.'))
  flags.add_argument(
      '--skip_pin_setup', action='store_true', help=(
          'Bypass the typical startup operation of configuring the I/O header '
          'pins. (Use this option if the header pins are pre-configured on '
          'boot by a device tree overlay.)'))
  flags.add_argument(
      '--skip_pru_restart', action='store_true', help=(
          'Bypass the typical startup cycle of stopping the PRUs, designating '
          'the firmware to run, and restarting the firmware. This option '
          'implies --skip_load_pru_firmware.'))
  flags.add_argument(
      '--skip_load_pru_firmware', action='store_true', help=(
          'Bypass the typical startup operation of designating the PRU '
          'firmware to run. (Use this option if the Cameo/Aphid PRU firmware '
          'is loaded automatically from /lib/firmware/am335x-pru0-fw and '
          '/lib/firmware/am335x-pru1-fw).'))
  flags.add_argument(
      'image_file', type=str, help=(
          'Path to the hard drive image file.'))

  return flags


# From here on, the code starts silly and gets more serious the further you go.

######################
#### LED blinking ####
######################
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

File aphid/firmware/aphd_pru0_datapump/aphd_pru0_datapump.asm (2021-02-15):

; Aphid: Apple parallel port hard drive emulator for Cameo
;
; Forfeited into the public domain with NO WARRANTY. Read LICENSE for details.
;
; This file: firmware for PRU 0
;
; PRU 0 is a "data pump" and parity calculator that controls the parallel
; port's data lines and \PPARITY signal. It operates in any of three modes:
;   1. Idling: it polls the data lines to compute the \PPARITY signal.
;   2. Reading: incoming data, clocked by \PSTRB, is stored in shared RAM;
;      the \PPARITY signal is also calculated as in idle mode.
;   3. Writing: outgoing data, clocked by \PSTRB, is served from shared RAM;
;      the \PPARITY signal is precomputed externally and also served from RAM.
;
; PRU 0 loops in idle mode by default. When it receives a host 1 interrupt
; (i.e. when PRU 1 issues a ePRU1to0 system event, i.e. when r31.t30 goes high),
; it examines the following command data structure at the low end of the shared
; memory space:
;
;   Byte 0: (reserved for "return code")
;        1: command; 0x00 for reading in data, 0x01 for writing data out
;      2-3: number of bytes/words to read in/write out
;      4-7: address (in PRU0's address space) to read/write data from/to.
;
; Immediately after receiving a host 1 interrupt for initiating a command, the
; PRU replaces the command byte with its bitwise complement. As host 1
; interrupts can also be used to terminate read and write modes prematurely
; (i.e. before all data has been transferred; see below), this precaution
; ensures that any terminating interrupt that arrives "too late" (and that would
; therefore be interpreted as a command initiation signal) will direct the PRU
; to execute a harmless invalid command.
;
; (As was just mentioned:) Read and write operations can be aborted by issuing a
; host 1 interrupt while the operation is in progress. In contrast with the
; command issuing procedure, a termination interrupt does not require any
; parameterisation or additional communication (e.g. preparation of values in
; shared memory).
;
; After entering a specified operating mode and completing the command provided
; (normally or abnormally), the PRU places a "return code" in byte 0 above and
; dispatches a host 0 interrupt. Return codes are:
;
;   0: Last operation was successful
;   1: Command dispatch unsuccessful (usually means: command unrecognised)
;   2: Read mode interrupted waiting for \PSTRB to go low
;   3: Read mode interrupted waiting for \PSTRB to go high
;   4: Write mode interrupted waiting for \PSTRB to go low
;   5: Write mode interrupted waiting for \PSTRB to go high
;
; There is an additional subtletly around return codes 4 and 5 when the
; interrupt arrives coincident to the very last outbound byte; see notes at the
; WRITE definition for details.
;
; Return code $FF is guaranteed never to be set by PRU 0. It's advisable to
; set this return code prior to issuing any data pump command; if you
; encounter it after you believe the completed, then the firmware has not
; completed the command yet and may never have begun.
;
; When reading, PRU 0 stores bytes from the data lines contiguously in memory,
; starting from the address specified in the command data structure. When
; writing, PRU 0 expects the memory at the specified address to contain a
; sequence of precomputed <data byte><parity byte> pairs: <data byte> will be
; placed onto the data lines, and the sixth bit of <parity byte> will be copied
; to the \PPARITY line. (All other <parity byte> bits are ignored, so it's safe
; to use values like 0x00 and 0xff.)
;
; Although the code in this file is arranged into "subroutine-like" blocks,
; there are no subroutines per se; the JAL instruction is not used. Instead,
; control jumps between the various blocks as shown:
;
;               read ordered ,--->[READ]----. read complete
;                            |              |
;                            |              v
;       ----->[INIT]----->[IDLE]<-------[REPORT]
;                            |              ^
;                            |              |
;              write ordered `--->[WRITE]---' write complete
;
; If it is necessary to reset PRU 0 to the IDLE state, the recommended procedure
; is to repeatedly issue host 1 interrupts with a command value of 0x80 in the
; shared memory data pump command data structure, awaiting a host 0 interrupt
; each time, until the "return code" accompanying the interrupt is ignored.
;
; The interrupt controller setup assumed by this firmware is described by a
; resource table definition in the accompanying file aphd_pru0_resource_table.c.
; Note that ordinarily an empty resource table is used in lieu of this
; definition, since it's expected that the PRU 1 firmware will specify
; interrupt controller configuration.
;
; Registers used:
;   Initialisation <INIT>:
;      R0: scratch
;      R1: scratch
;   Awaiting a command <IDLE>
;      R2: scratch
;   Reading a byte off of the data lines <mRead>:
;      R3: data in
;   Writing a byte onto the data lines <mWrite>:
;      R4: data out
;   Computing parity for last byte read off of the data lines <mParity>:
;      R5: scratch
;   Idling and then interpreting the command data structure <IDLE>:
;      R6: command data structure, first half
;      R7: read/write memory buffer pointer
;   Externally-clocked multiple byte reads <READ>:
;      R8: address receiving the next byte read from the data lines
;      R9: one byte beyond the address receiving the last byte
;     R10: scratch
;   Externally-clocked multiple byte writes <WRITE>:
;     R11: address of the next word to send out over the data and parity lines
;     R12: two bytes beyond the address of the last word to send
;     R13: scratch
;
;   Statistics:
;     R15: total bytes the datapump has been requested to read in
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

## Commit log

2018-08-12 Cameo and Aphid full initial commit
    [cameo_cape-B.Paste.gbr, cameo_cape-B.SilkS.gbr, cameo_cape-Bottom.gbr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]
2018-08-12 Correct resistor value in SMD component layout images.
2018-10-20 Update for the 2018-10-07 BeagleBoard.org image
    Plus a small progress report on signal termination for longer cables.
2018-12-07 Add 100Ω inline terminating resistors to most Aphid signal lines.
2021-01-23 Cameo/Aphid: Fix overly picky PRU1 state machine timing
    Waiting for a particular coincidence of \PCMD high and PR/\W low could lock up PRU0 for
    nearly 11 seconds if non-handshake activity on the control lines wiggled \PCMD and PR/\W
    together in a confusing way (specifically, in a way that left PR/\W high or had PR/\W go
    from low to high very quickly). The initialisation routine for the parallel interface
    card was prone to generating these toxic wiggles, but owing to vagaries of signal
    propagation and other electrical mysteries, a Cameo/Aphid device would only be affected
    by it if it was plugged into the top port. This change relaxes the coincidence check so
    that a \PCMD-raise with PR\/W high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
    [aphd_pru1_control.cc]
2021-01-23 Cameo/Aphid selector: HelloBootDrive interprets $00 drive IDs correctly on Lisa 2/10s
    012345678 012345678 012345678 012345678 012345678 012345678 012345678 012345678
    HelloBootDrive now converts device ID $00 to $02 on Lisa 2/10 systems, fixing a
    bug where the Selector would not believe on startup that the built-in parallel port
    (which it knows as $02) had a Cameo/Aphid attached.
2021-01-23 Cameo/Aphid selector: HelloBootDrive interprets $00 drive IDs as $02 on 2/10s
    bug where the Selector would not believe on startup that the built-in parallel
    port (which it knows as $02) had a Cameo/Aphid attached.
    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
2021-02-02 Cameo/Aphid: Device tree overlay + firmware autoload for fast boot
2021-02-12 Cameo/Aphid: correct double-negative in firmware loading
    [profile.py]
2021-02-16 Cameo/Aphid: Selector v0.8 and miscellaneous other convenience items
    Selector: Bounded status string printing to avoid screen mess if the Cameo/Aphid
    goes offline.
    Filesystem plugin: Addition of a 'mx' command for creating arbitrarily-sized
    drive images.
    Utility: addition of a diagnostic script for snooping on PRU1 by peeking into
    ARM/PRU shared memory space.
    [profile_plugin_FFFEFE_filesystem_ops.py]
2021-02-24 Cameo/Aphid: Correct mis-assembly of the Selector
    The Selector floppy disk image should include the ProFile I/O library
    The Selector hard drive image should not
    It had been reversed, but it's corrected now
2021-02-28 Cameo/Aphid Selector 0.9: image creation size option, and more
    Catalogue display shows the sizes of drive images
    Bugfix for text input setup when editing long strings
    [profile_plugin_FFFEFE_filesystem_ops.py]
2021-03-28 Cameo/Aphid Selector 1.0: power button, floppy eject, autoboot password, bugfixes
2021-09-08 added arcanebyte designs
    [cameo.brd, cameo.sch, cameo_top_bom.csv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]

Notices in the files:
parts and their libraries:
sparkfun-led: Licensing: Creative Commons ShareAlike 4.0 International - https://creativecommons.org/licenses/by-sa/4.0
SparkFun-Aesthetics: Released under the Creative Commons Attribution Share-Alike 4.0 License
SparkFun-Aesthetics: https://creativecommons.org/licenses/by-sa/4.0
